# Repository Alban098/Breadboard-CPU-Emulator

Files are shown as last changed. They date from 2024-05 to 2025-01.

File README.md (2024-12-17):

# Breadboard CPU Emulator


## Compiler

This CLI will compile an assembly file into a .rom file that can be executed by the emulator and ran on the actual Breadboard computer (WIP).

See [assembly details](docs/assembly.md) for more details on the Assembly language itself.

### Usage
You can compile a file by passing the following parameter to the CLI of the compiler.
```
java -jar compiler.jar -f sample.asm -o sample.rom
```
if no ``-o X`` is passed, the binary file will be saved with the same name as the input file with a ``.rom`` extension.

## Emulator
The emulator is based on real world breadboard computer inspired by [this project](https://eater.net/8bit) that is not yet finished.

To run a binary file, just pass its path as an argument to the emulator.

### ROM & Instructions dumps
To facilitate physical assembly and proper emulation from instruction opcode down to signal indices in the control words,
the emulator has the ability to dump the content of it's program ROM, both in ["humanly readable format"](dump/ROM_dump.md) and as the binary blob that should be written to the 3 EEPROM that will be located in the **Control Unit** :
- [Dump 0](dump/ROM_dump.bin0) for the 8 least bits of the **Control Word**
- [Dump 1](dump/ROM_dump.bin1) for the 8 middle bits of the **Control Word**
- [Dump 2](dump/ROM_dump.bin2) for the 8 most significant bits of the **Control Word**

The emulator can also dump the [current instruction set](dump/instruction_set.md).

## Physical Computer
More details about the Breadboard computer in itself can be found [there](docs/modules.md), along with the full [parts list](docs/parts_list.md)

### EEPROM Programmer
That build uses some 28C series EEPROM to emulate large combinatorial logic, those will need to be programmed

I used that **EEPROM Programmer** : https://tomnisbet.github.io/TommyPROM/docs/hardware
If like me, you used an **Arduino Nano Every** instead of a **Nano V3** for the **EEPROM Programmer**, that Programmer will need some rework to actually work as intended (see [this repo](https://github.com/Alban098/TommyPROM-ATMEGA-4809) for the adapted code and wiring diagram)

## Roadmap
* [x] Instruction set
* [x] Assembly compiler
* [x] Emulator
  * [x] Components
  * [x] Signals
  * [x] Instructions
* [x] Documentation
* [x] Electrical diagrams
* [x] Electronic components ordering
* [ ] Physical assembly
  * [x] Clock module
  * [x] Program counter
  * [x] Registers
  * [x] ALU
  * [x] Status register
  * [x] Memory modules
  * [ ] Control Unit
  * [x] [Arduino Programmer](docs/programmer.md)

## Images




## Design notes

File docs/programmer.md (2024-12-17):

# 8 bits Breadboard Computer - Arduino Programmer

Having **64 KB of addressable space**, manually programming that computer through the **DIP switches everytime it is powered up** became unrealistic.
So the need for an automated way to upload programs became essential.

I was short on parts, so I had the idea of repurposing the **EEPROM programmer** used for the **Control Unit and the Output Register**. to also be able to program this Computer.

To achieve that, the simples way was to add 2 connection ports right next to the DIP switches, and to connect the **address and data pins** of the EEPROM Programmer, and hard-wiring the **Program Switch** to the **Write signal** of the EEPROM Programmer
This enables us to send binary files directly though **XMODEM protocols** using the serial port of the Arduino.

Doing it in that way introduced 2 limitations :
- First limitation of that approach is that we need to manually switch the Computer into programming mode for the process to actually succeed, 
- Second limitation is that we can't leverage the read capabilities of the EEPROM programmer as the DIP switch where we connected it are isolated from the RAM module output

Implementation details can be found [here](https://github.com/Alban098/TommyPROM-ATMEGA-4809)



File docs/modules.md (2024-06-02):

# 8 bits Breadboard Computer - Electronic diagrams

## Registers
This computer has **3 working registers**, used for general purpose computations, and an **output register**

### [A Register](modules/a_register.md)
This register is the main working register, it has **read** and **write** capabilities and is directly connected to the ALU.

Its main purpose is to store the **primary operand** of any computation.
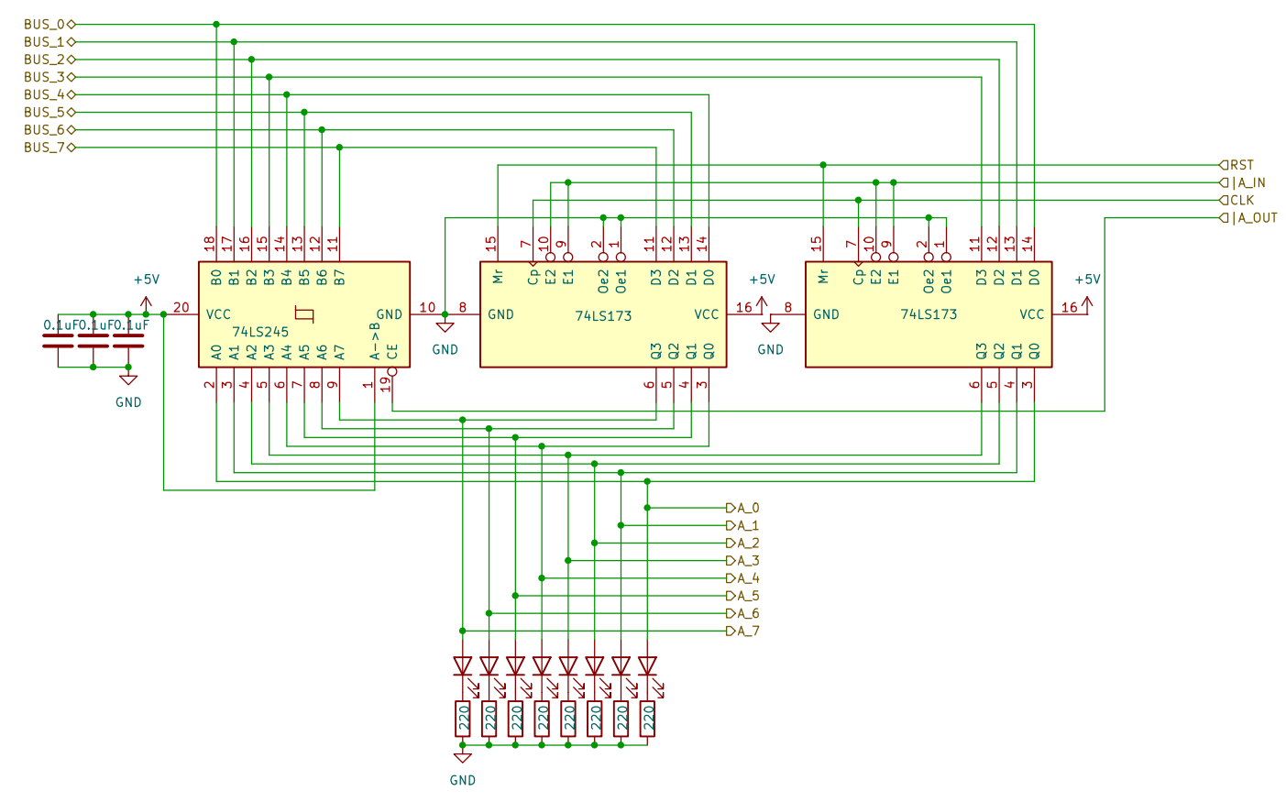
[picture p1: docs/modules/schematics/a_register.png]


### [B Register](modules/b_register.md)
This register is the secondary working register, it only has **write** capabilities and is directly connected to the ALU.

Its purpose is to store the **secondary operand** of any computation.
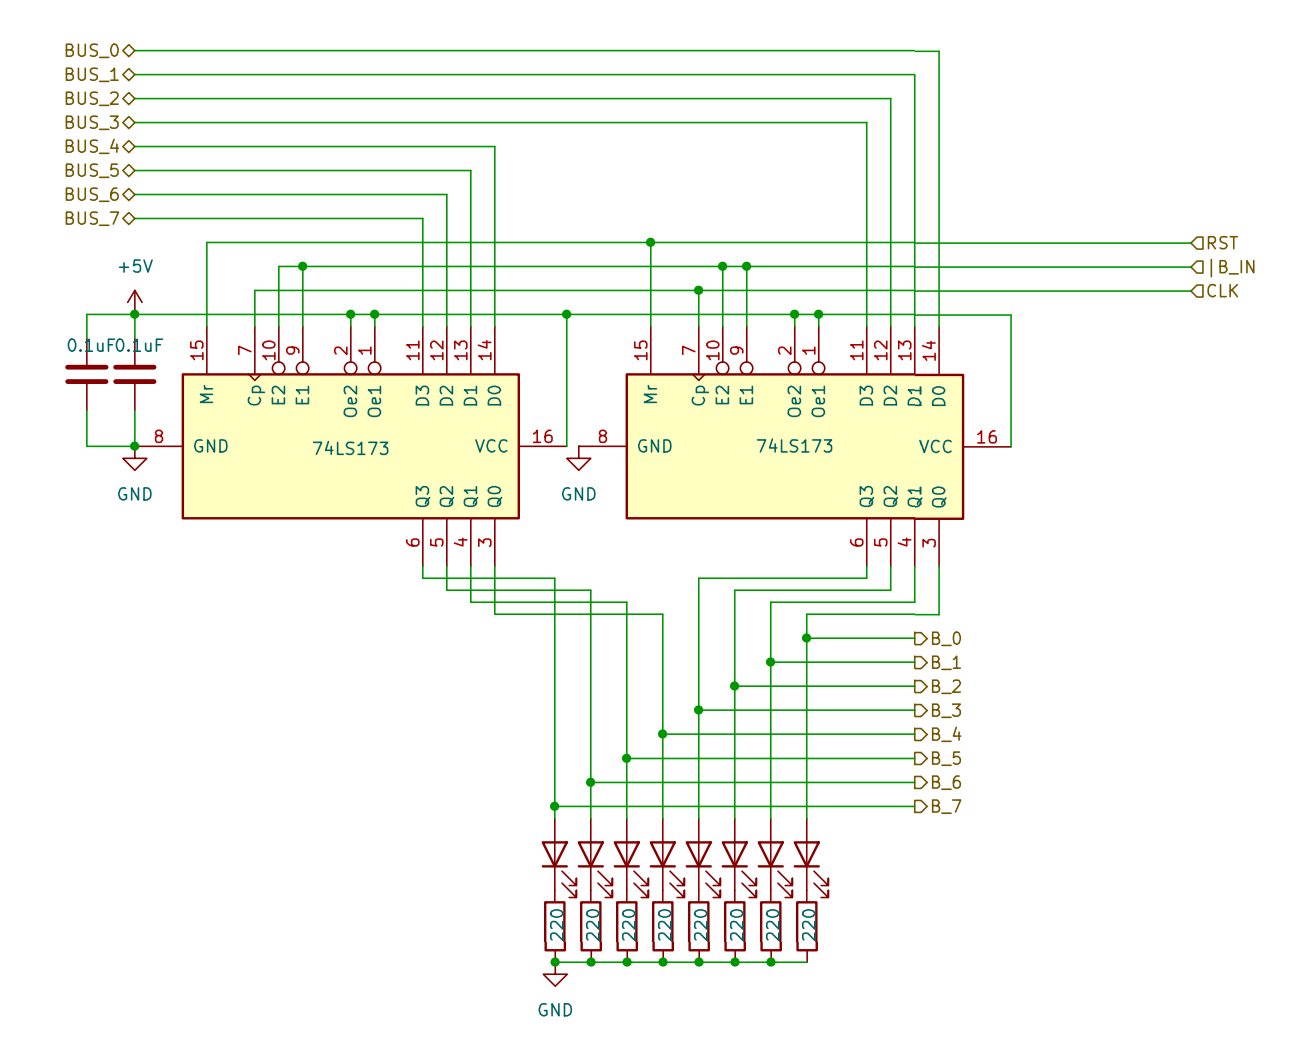
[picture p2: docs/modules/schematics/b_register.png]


### [HL Register](modules/hl_register.md)
This register is used to 'buffer' 16 bits memory addresses, 16 bits values can be written to it using only the 8 LSB of the BUS

It is widely used for memory addressing and branching instruction
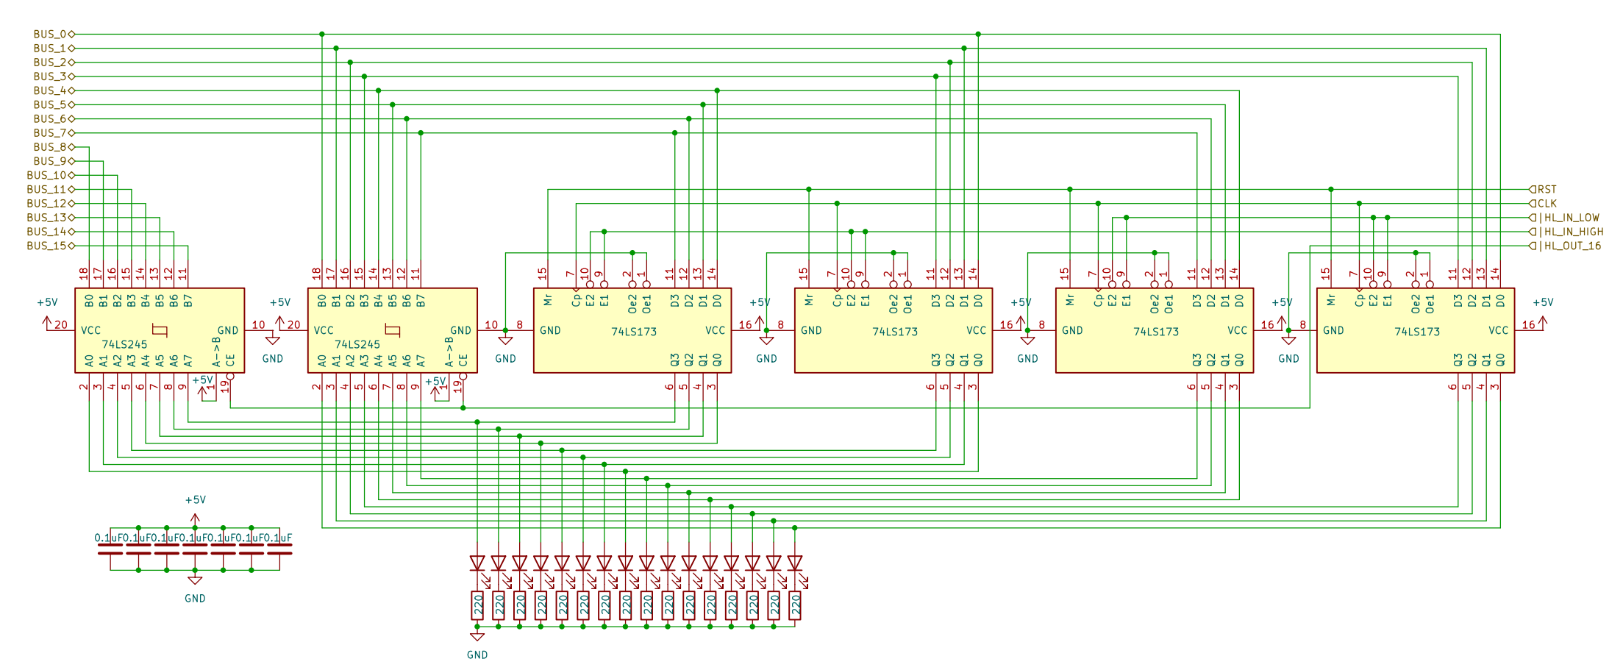
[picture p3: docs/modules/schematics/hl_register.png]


### [Output Register](modules/output_register.md)
This register has one purpose, to display the result of a computation in a user-friendly manner, it only has **write** capabilities and display can be switch from signed to unsigned. 
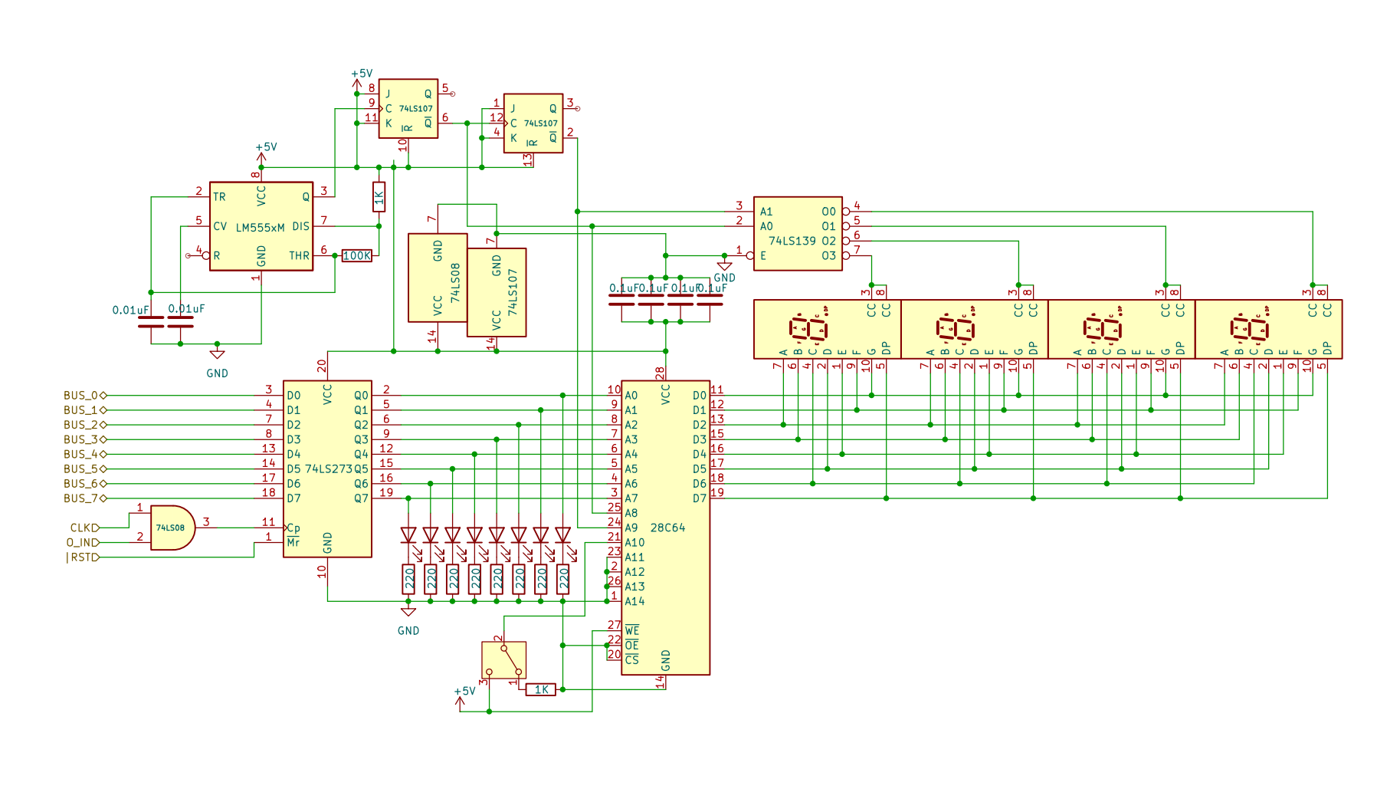
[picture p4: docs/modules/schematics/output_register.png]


## Memory Management
In this computer, **RAM reads and writes** are totally **synchronous**, and no slower to access than any registers.
Memory address is selected using the **Memory Address Register** after that, **Memory** operate juste like any other register.

### [Memory Address Register](modules/memory_address_register.md)
This register's only purpose is to hold the currently selected memory address, it's output is directly connected to the address lines of the **Memory module**

It also holds control over "Manual programming mode" using a static switch, in this state, the memory address pointer is controller by 2 8DIP switch.

This register can hold a 16 bits address
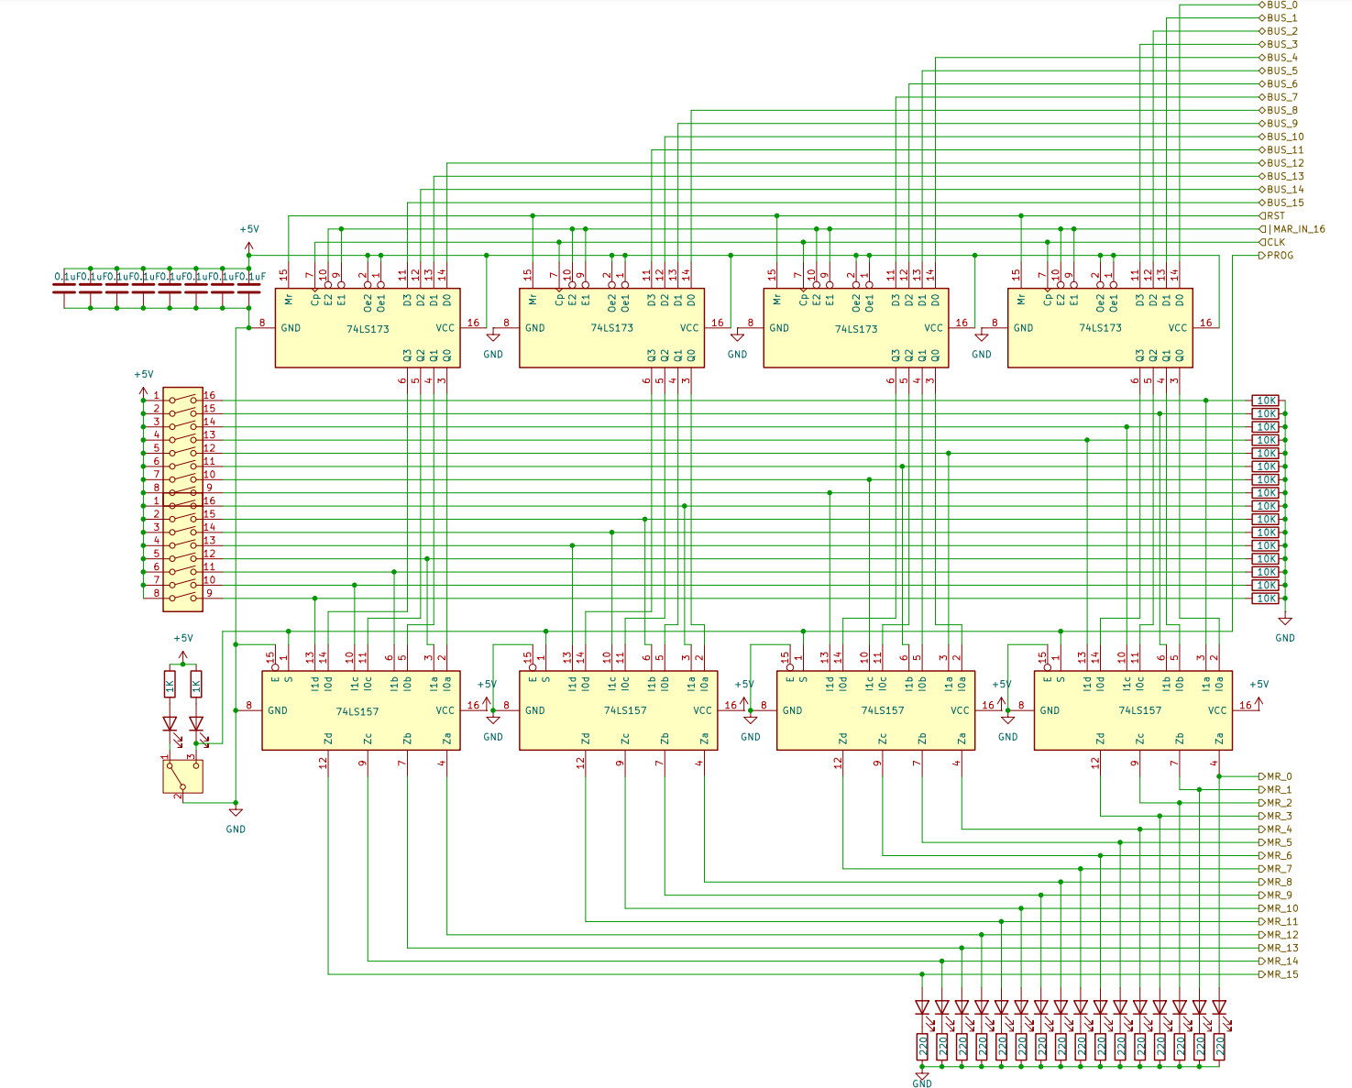
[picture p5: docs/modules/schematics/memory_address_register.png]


### [Memory](modules/memory.md)
The memory module is responsible to hold all the data of the computer and should be capable of being addressed by an 8 bit value.

This module is enslaved to the **Memory Address Register**'s **Manual programming mode** switch, in this state, the written value is controlled by an 8DIP switch.
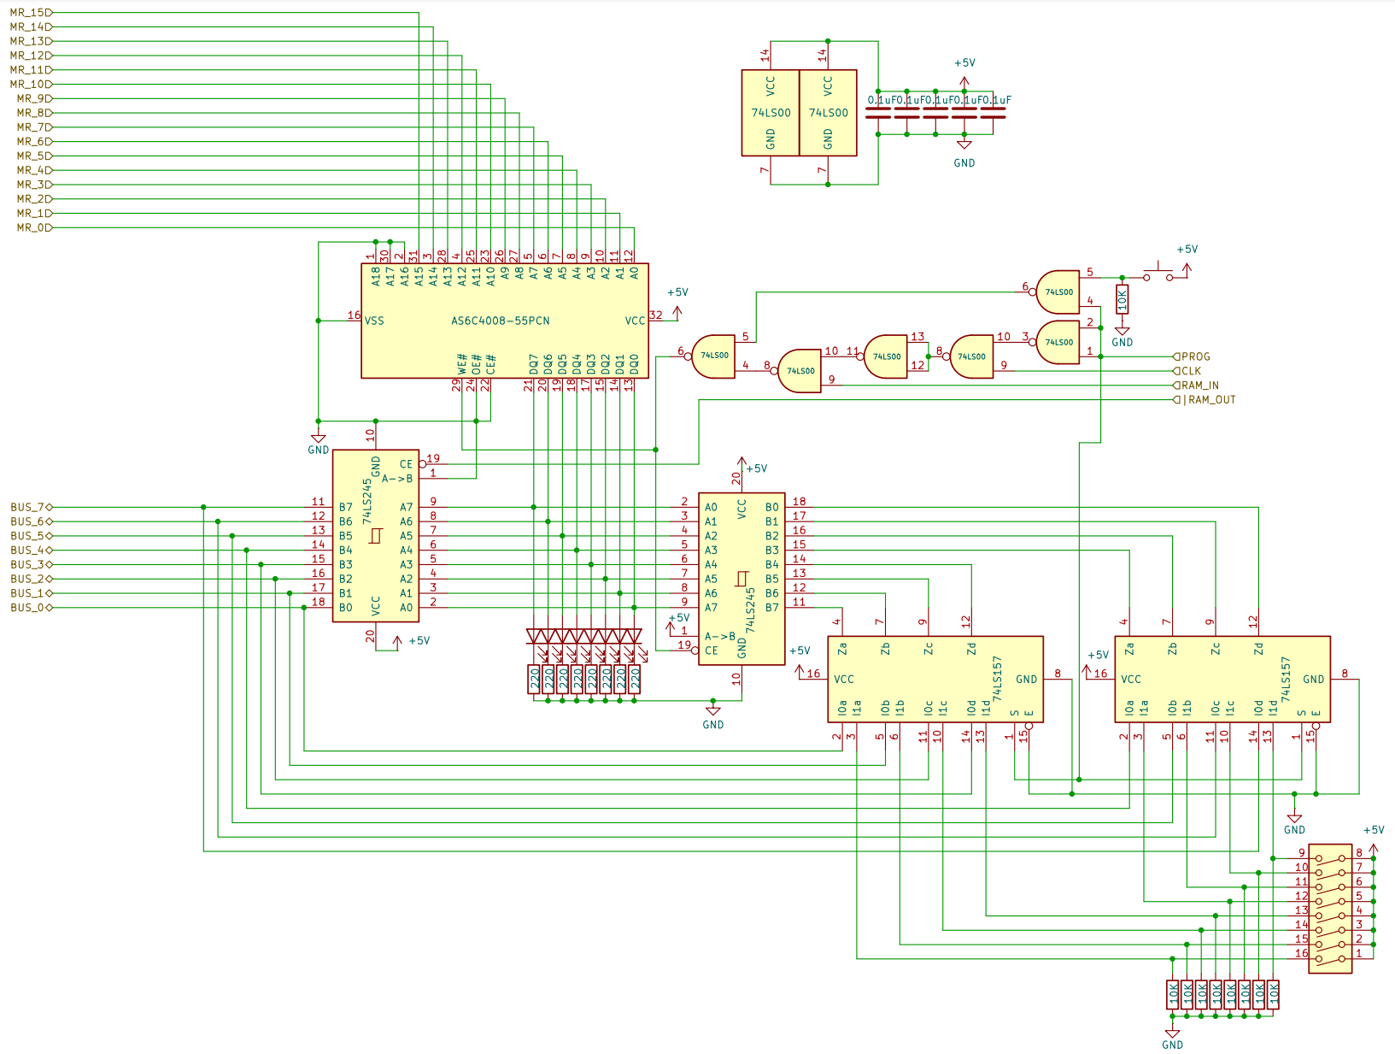
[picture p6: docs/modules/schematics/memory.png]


## Execution Logic
The execution logic is composed of 3 primary components, responsible for addressing, executing and keeping track of the current state and instructions.

### [Program Counter](modules/program_counter.md)
The program counter is responsible for keeping track of where in the execution the computer currently is, it has the ability to be programmatically set by branching instructions

The program counter can count up to #FFFF, and is one of the few modules that can exploit the entire 16 bit bus
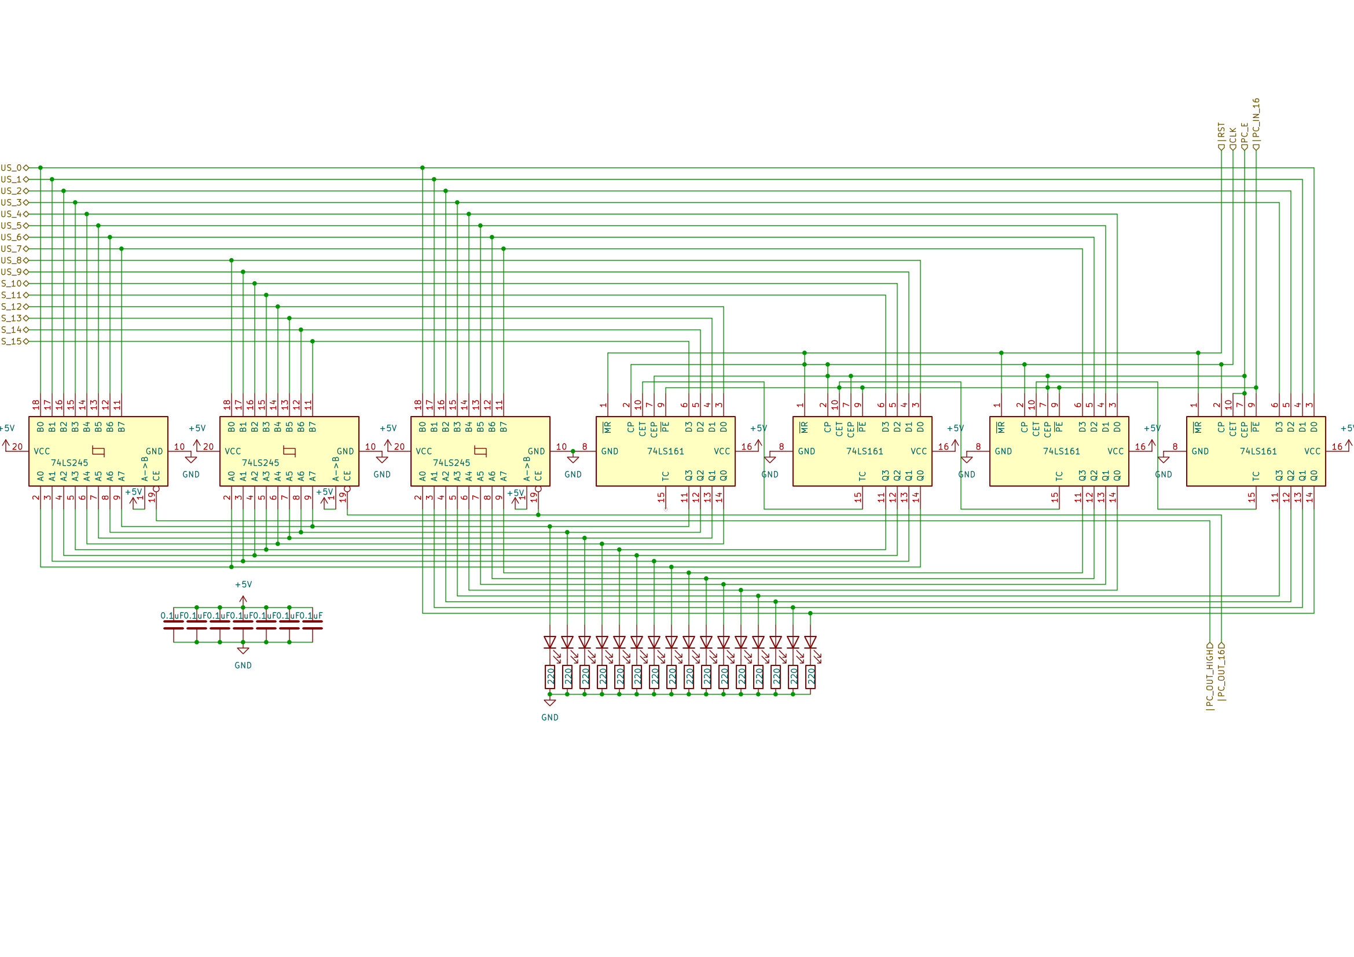
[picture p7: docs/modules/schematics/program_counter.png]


### [Arithmetic Unit](modules/alu.md)
The alu is the main brain of the computer, it's the component that actually perform computation and is the only way to interact with the status register and execute conditional branching instructions
It has 2 modes, the first being simple addition, the second being 2's complement subtraction (A - B)
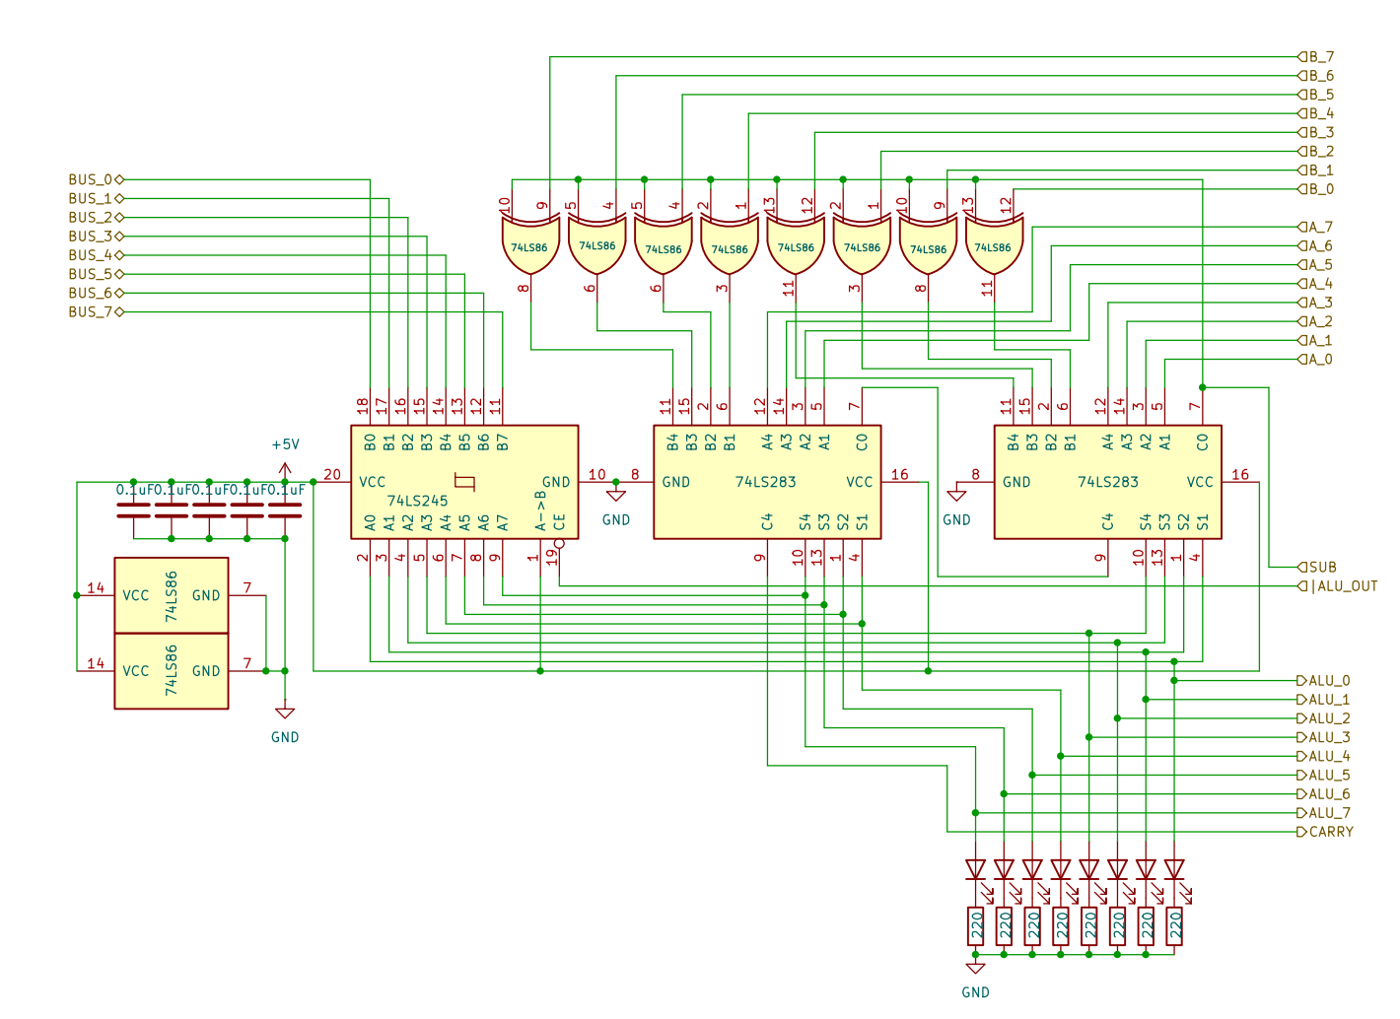
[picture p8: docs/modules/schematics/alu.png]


### [Status Register](modules/status_register.md)
The last component of the execution logic is the status register, it holds **Flags** regarding the last computation.

The 4 flags are :
- **Overflow** if the result has changed sign, this flag is only relevant if you consider your values as signed integers.
- **Zero** if the result of the computation is 0.
- **Carry** if the previous operation has produced a carry to ripple out of the 8 bit range.
- **Negative** if the most significant bit of the result is set to 1, meaning a negative number if in signed mode .
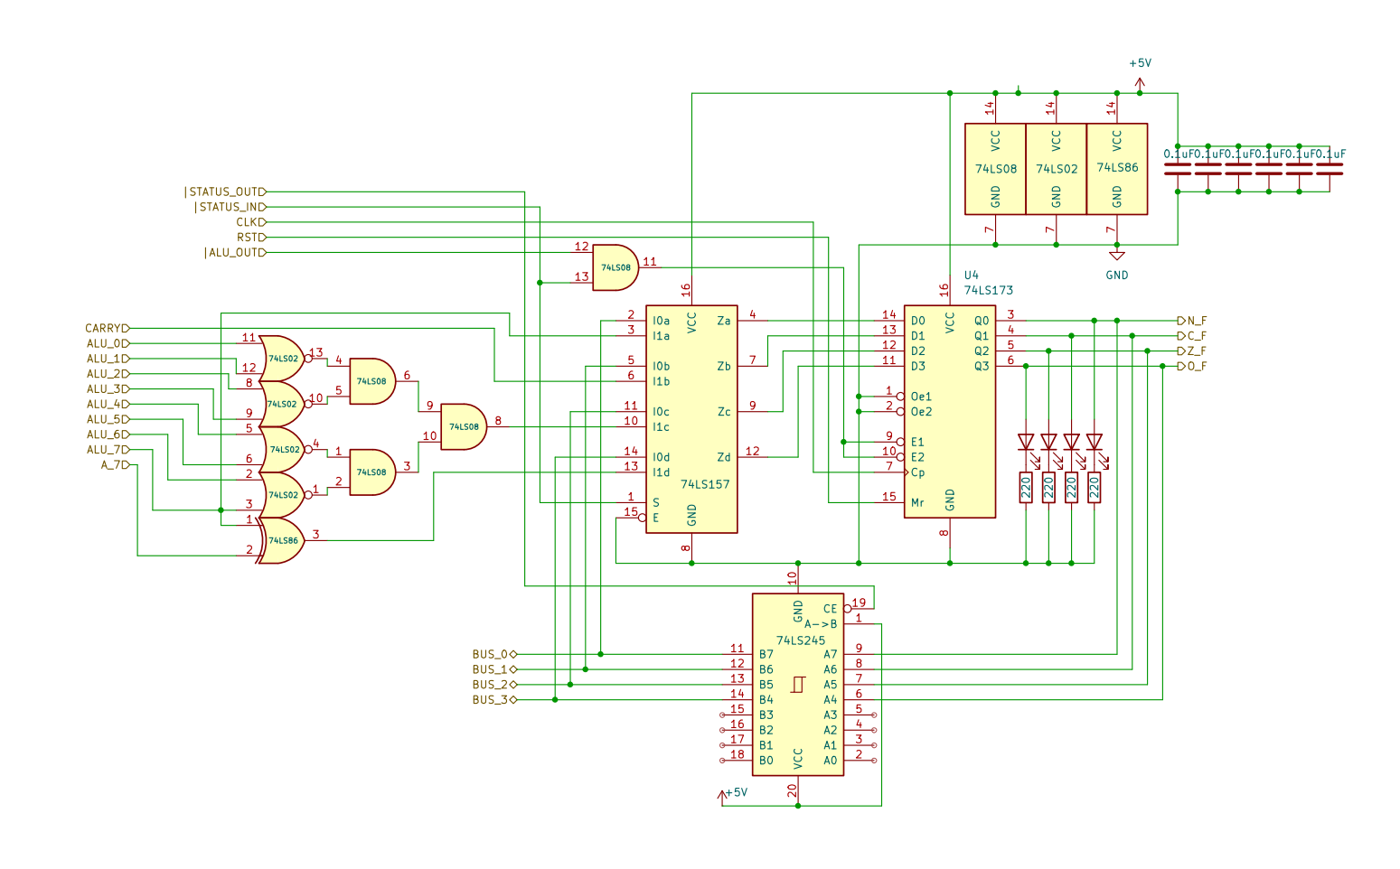
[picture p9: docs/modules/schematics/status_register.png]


### [Stack Pointer](modules/stack_pointer.md)
This register is used to hold the current stack pointer, it is hardware wise an 8 bits register, but is read as a 16bit register, with the 8 MSB set to HIGH, effectively this restricts the stack to the last memory page

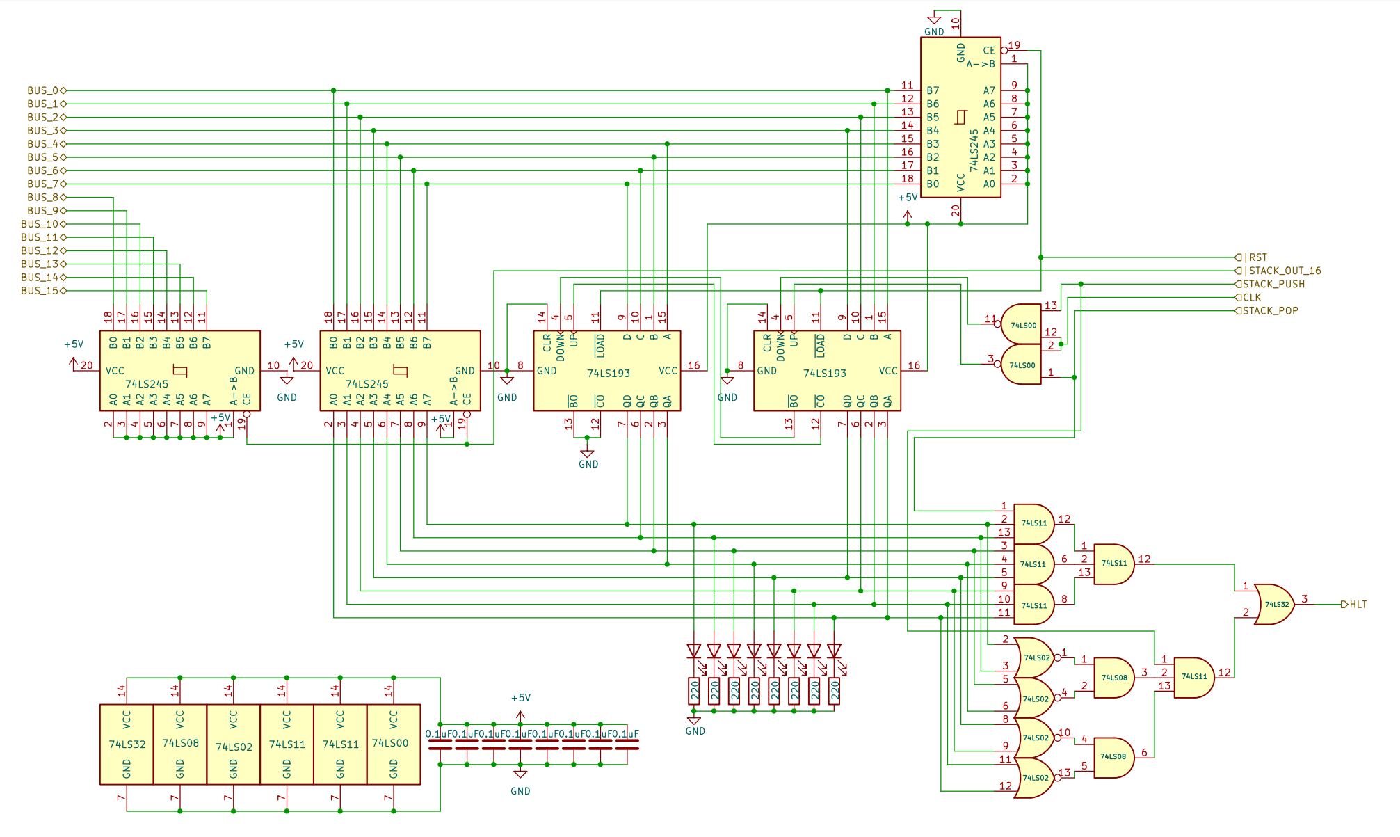
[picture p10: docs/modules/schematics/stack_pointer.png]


## Control Logic
The last key part of the computer, is the control logic that will enable every component to work together as one unit.

### [Clock Module](modules/clock.md)
The clock module is at the bottom of the pyramid, it dictat the rythme to all other component and synchronize them.

This module can operate on itself or switch to "Manual" mode, in which the clock signal is controller by a psh button for debug purposes.
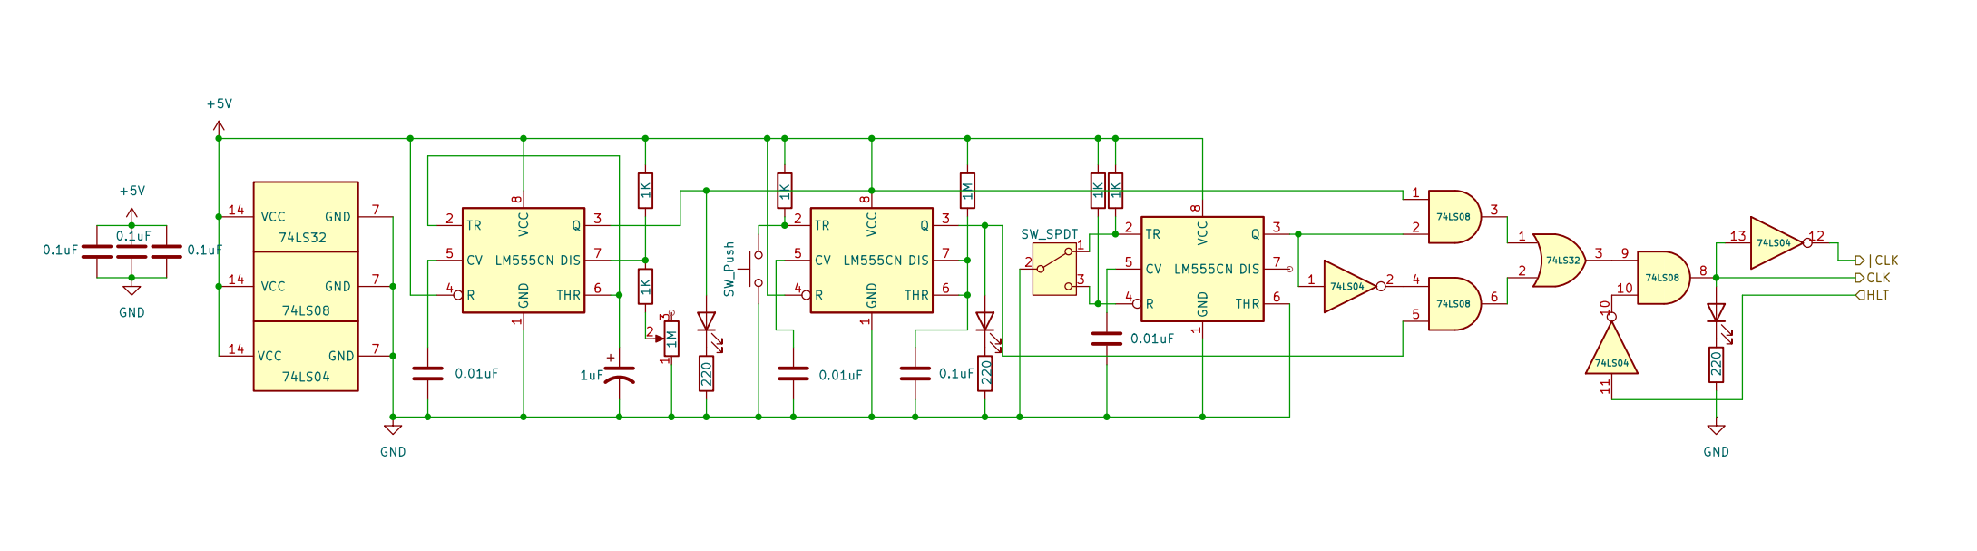
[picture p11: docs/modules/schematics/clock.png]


### [Instruction Register](modules/instruction_register.md)
The instruction register is similar to the **Memory Address Register** but hold the opcode of the currently executing instruction.

Its output is directly connected to the **Control Unit**
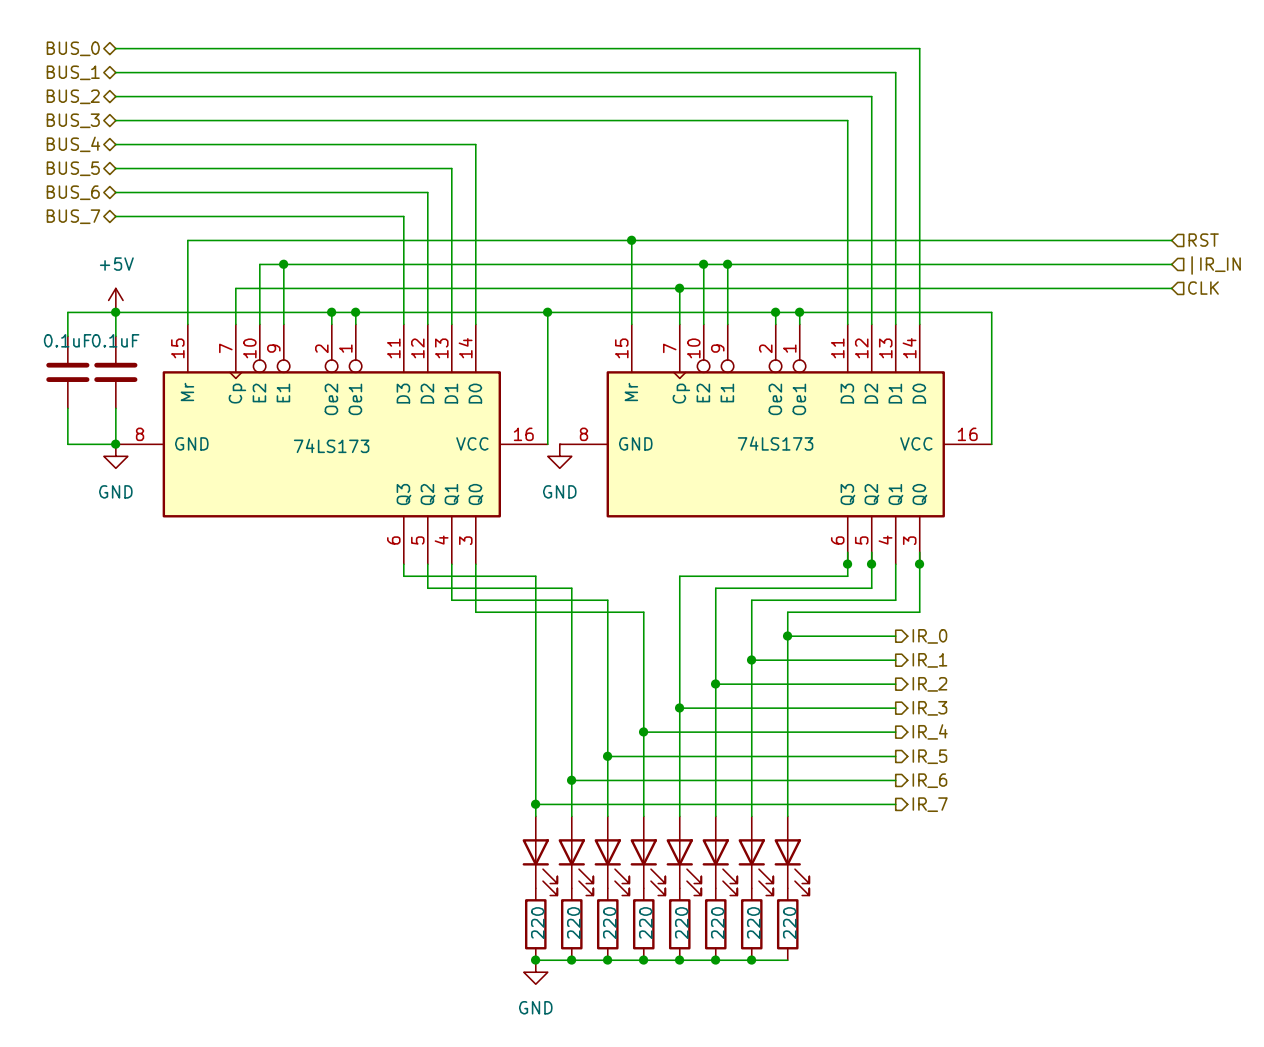
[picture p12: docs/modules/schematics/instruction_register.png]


### [Control Unit](modules/control_unit.md)
Finally, the last component is one of the most important, as it will tell each other component, what to do and when to do it depending on the current execution context 
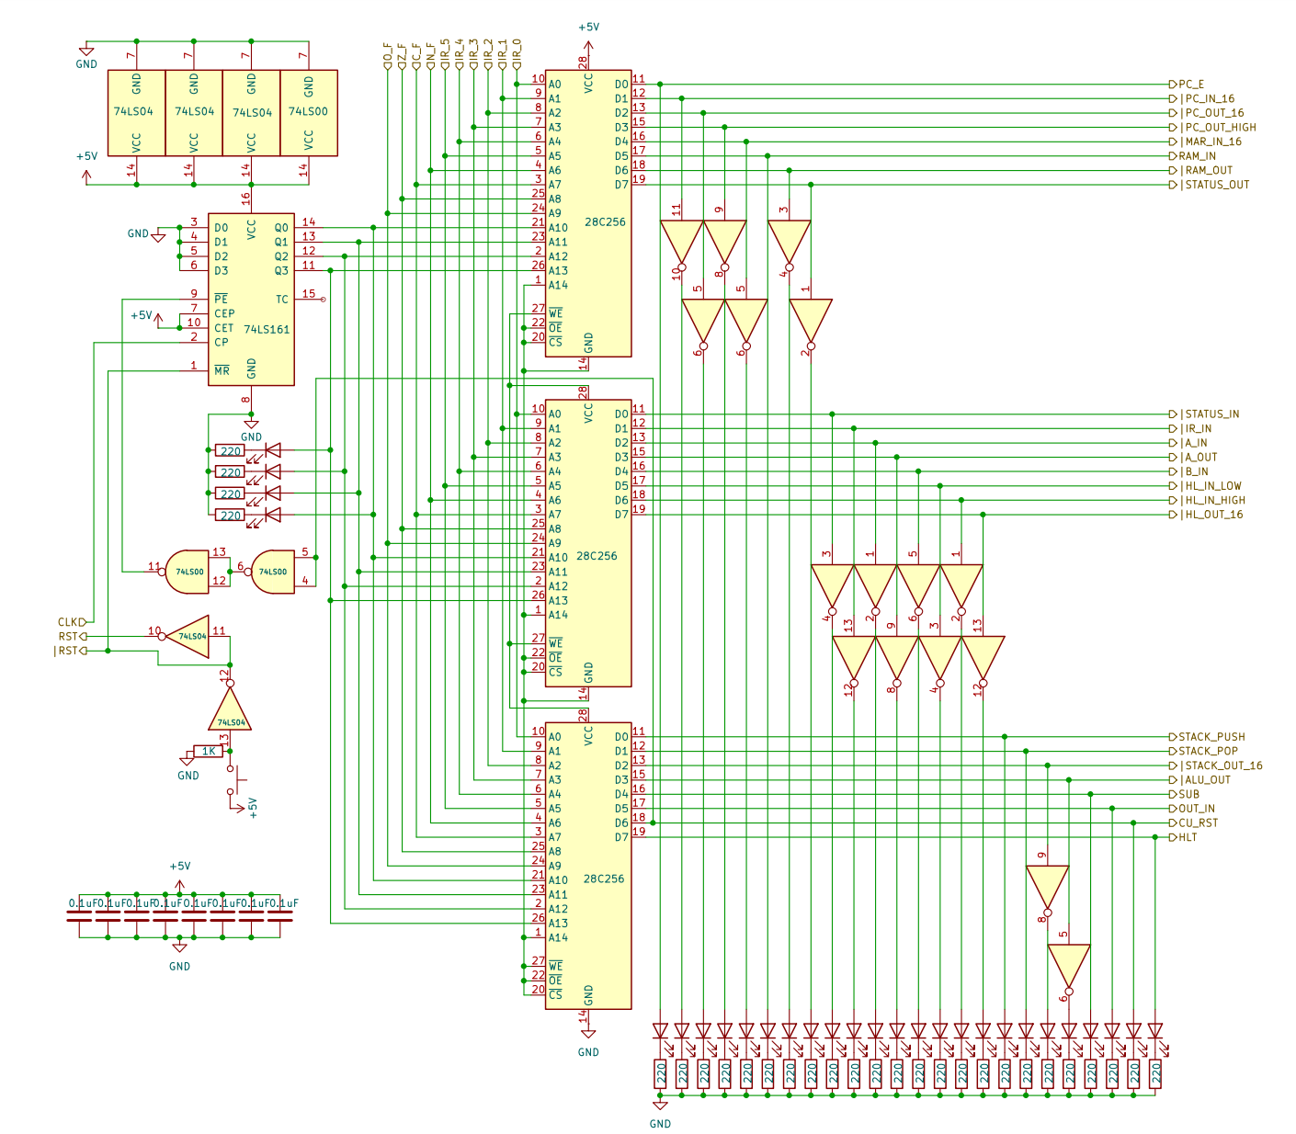
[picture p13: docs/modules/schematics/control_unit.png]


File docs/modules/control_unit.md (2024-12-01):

# 8 bits Breadboard Computer - Control Unit

## Diagram


## Description
Internally, each instruction has a certain number of micro-steps, this is handled by a 4bits counter that will keep track of the current micro-step.
Each instruction should therefore have a last micro-step that is responsible for resetting the counter.

The 3 EEPROMs are used as combinational logic substitutes, the address is of the form
```
Step(4bit)_Flags(4bit)_opcode(6bit)
```
The RST signal is controlled by a Push Switch on this module
The CLK signal will be used to increase the Step Counter

A subset of signals is inverted, this is due to the fact that in their respective modules, they are **Active_LOW**, due to that, the EEPROM will default them to 1 and set them to 0, this way, we only need inverters for displaying purposes, but they can be removed from the build if not needed

! In the Emulator, state represent what is displayed and not what actually is in the EEPROM, all signals are considered **ACTIVE_HIGH** by the Emulator !

### Signals
| Signal | Mode | Binary mask | Description |
|:---|---:|:---:|---:|
| CLK | Active_HIGH | X | The main clock signal |

### I/O
| Name | Size | Type | Description |
|:-----|---:|-----:|---:|
| IR | 6 bits | In | The 6 least significant bits of the Instruction Register |
| *_F  | 4 bits | In | The 4 least significant bits of the Status Register |

## Parts list
| Part | Quantity |
|:---|---:|
| Breadboard BB830 | 3 |
| 220Ω Resistor | 28 |
| 0,1µF Capacitor | 8 |
| CD74HCT00E (4x 2-NANDs) | 1 |
| CD74HCT04E (8x Inverters) | 3 |
| CD74HCT161E (4 bits Counter) | 1 |
| AT28C256-15PU | 3 |
| Yellow LED | 4 |
| Blue LED | 24 |
| Push Button | 1 |

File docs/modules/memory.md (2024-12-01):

# 8 bits Breadboard Computer - Memory

## Diagram


## Description
The module can be switched in **Manual Programming Mode** (this is controlled by the Memory Address Register), in that state, the value read from the bus is overridden by a 8DIP Switch, and the clock and **RAM_IN** signals are overridden by a Push Switch.

### Signals
| Signal  | Mode | Binary mask | Description |
|:---|---:|:---:|---:|
| RAM_IN  | Active_HIGH | 0000_0000_0010_0000 | Will capture the BUS's value at the next @CLK and store it at the selected address |
| RAM_OUT |  Active_LOW | 0000_0000_0100_0000 | Puts the current value at the selected address on the BUSS |
| PROG | Active_HIGH | X | Will set the module in **Manual Programming Mode** |
| CLK | Active_HIGH | X | The main clock signal |

### I/O
| Name | Size | Type | Description |
|:-----|---:|---:|---:|
| BUS  |  8 bits | In / Out | Direct connection to the BUS |
| MAR  | 16 bits | In | Direct output of the **Memory Address Register** |

## Parts list
| Part | Quantity |
|:---|---:|
| Breadboard BB830 | 2 |
| 220Ω Resistor | 8 |
| 10kΩ Resistor | 9 |
| 1nF Capacitor | 1 |
| 0,1µF Capacitor | 5 |
| CD74HCT00E (4x 2-NANDs) | 2 |
| CD74HCT157E (2 lines to 1 bit Encoder) | 2 |
| CD74HCT245E (8 bits Bus Transceiver) | 2 |
| AS6C1008-55PIN | 1 |
| Red LED | 8 |
| 8 bits DIP switch | 1 |

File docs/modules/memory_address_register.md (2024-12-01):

# 8 bits Breadboard Computer - Memory Address Register

## Diagram


## Description
This register holds the pointer of the current RAM address, it also controls the **Manual Programming Mode** switch

### Signals
| Signal | Mode | Binary mask | Description |
|:---|---:|:---:|---:|
| MAR_IN_16 |  Active_LOW | 0000_0000_0000_0000_0001_0000 | Will capture the BUS's value at the next @CLK |
| RST | Active_HIGH | X | Reset the register's value to 0 |
| CLK | Active_HIGH | X | The main clock signal |

### I/O
| Name | Size | Type | Description |
|:-----|---:|-----:|---:|
| BUS  | 16 bits | In | Direct connection to the BUS |
| MR | 16 bits |  Out | Output of the register |
| PROG |  1 bits |  Out |  Will set the module in **Manual Programming Mode** |

## Parts list
| Part | Quantity |
|:---|---:|
| Breadboard BB830 | 2 |
| 220Ω Resistor | 16 |
| 1kΩ Resistor | 2 |
| 10kΩ Resistor | 16 |
| 0,1µF Capacitor | 8 |
| CD74HCT173E (4 bits Register) | 4 |
| CD74HCT157E (2 lines to 1 bit Encoder) | 4 |
| Yellow LED | 1 |
| Green LED | 1 |
| Red LED | 16 |
| 8 bits DIP switch | 2 |
| Toggle Switch | 1 |

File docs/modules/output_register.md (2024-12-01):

# 8 bits Breadboard Computer - Output Register

## Diagram


## Description
This register will display its value as a decimal value that can be signed or not.

It will drive 4 7 segments display using the same data lines and one EEPROM. this is managed by rapidly switching on and off each display and relying on persistence of vision.

To do so we use a 555 Timer to get a consistent clock signal, and use 2 JK-Flip-Flop to simulate a 2 bit binary counter, this value is used as the 2 MSB of the EEPROM Address to differentiate each digit of a number.
We also use a 2bit to 4 lines selector to activate and deactivate each display one at a time.
This will have the effect of making each display show a different number, creating the illusion of driving all the 7 segment displays at the same time with a quarter of the data lines 

A Switch can control if the value is displayed as signed or not.

! Don't forget to tie signals of the additional flip-flop of the 74HCT107 to GND to avoid potential interference in the display !

Find [here](../../dump/output_register_eeprom_dump.bin) the EEPROM content associated with this wiring

### Signals
| Signal | Mode | Binary mask | Description |
|:---|---:|:---:|---:|
| OUT_IN | Active_HIGH | 0010_0000_0000_0000_0000_0000 | Will capture the BUS's value at the next @CLK |
| RST |  Active_LOW | X | Reset the register's value to 0 |
| CLK | Active_HIGH | X | The main clock signal |

### I/O
| Name | Size | Type | Description |
|:-----|---:|---:|---:|
| BUS  | 8 bits | In | Direct connection to the BUS |

## Parts list
| Part | Quantity |
|:---|---:|
| Breadboard BB830 | 2 |
| 220Ω Resistor | 8 |
| 1kΩ Resistor | 2 |
| 100kΩ Resistor | 1 |
| 0,01µF Capacitor | 2 |
| 0,1µF Capacitor | 4 |
| LM555CN (Timer) | 1 |
| CD74HCT08E (4x 2-ANDs) | 1 |
| CD74HCT107E (Dual JK-Flip-Flops) | 1 |
| CD74HCT139E (2 bits to 4 lines Decoder) | 1 |
| CD74HCT273E (8x D-Flip-Flops) | 1 |
| AT28C64B-15PU | 1 |
| Red LED | 8 |
| Toggle Switch | 1 |
| 7 Segments Display | 4 |

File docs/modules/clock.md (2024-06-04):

# 8 bits Breadboard Computer - Clock Module

## Diagram


## Description
The 3 LM555CM timers each have a different purpose :
- The first one is in **astable** mode, providing a regular clock signal that is length controllable using the variable resistor.
- The second one is a **monostable** and serve as a filter to debounce the Push Switch's clock signal will manual stepping.
- The last one is a **bistable** and serve the same purpose as the monostable one but for the mode switching switch.

### Signals
| Signal | Mode | Binary mask | Description |
|:---|---:|:---:|---:|
| HLT | Active_HIGH | 1000_0000_0000_0000_0000_0000 | Prevent any clock cycle from occurring |

### I/O
| Name | Size | Type | Description |
|:-----|---:|---:|---:|
| CLK  | 1 bits | Out | The main clock signal |
| ~CLK | 1 bits | Out | The main clock signal, but inverted |

## Parts list
| Part | Quantity |
|:---|---:|
| Breadboard BB830 | 1 |
| 220Ω Resistor | 3 |
| 1kΩ Resistor | 5 |
| 1MΩ Resistor | 1 |
| 1MΩ Potentiometer | 1 |
| 0,1µF Capacitor | 4 |
| 0,01µF Capacitor | 3 |
| 1µF Capacitor | 1 |
| Toggle Switch | 1 |
| Push Button | 1 |
| LM555CN (Timer) | 3 |
| CD74HCT04E (8x Inverters)  | 1 |
| CD74HCT08E (4x 2-ANDs) | 1 |
| CD74HCT32E (2x 4-ORs) | 1 |
| Green LED | 2 |
| Blue LED | 1 |

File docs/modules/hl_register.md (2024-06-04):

# 8 bits Breadboard Computer - HL Register

## Diagram


## Description

### Signals
| Signal | Mode | Binary mask | Description |
|:---|---:|:---:|---:|
| HL_IN_LOW  |  Active_LOW | 0000_0000_0010_0000_0000_0000 | Will capture the BUS's value in the 8 LSB at the next @CLK |
| HL_IN_HIGH |  Active_LOW | 0000_0000_0100_0100_0000_0000 | Will capture the BUS's value in the 8 MSB at the next @CLK |
| HL_OUT_16  |  Active_LOW | 0000_0000_1000_1000_0000_0000 | Writes the current value to the BUS |
| RST | Active_HIGH | X | Reset the register's value to 0 |
| CLK | Active_HIGH | X | The main clock signal |

### I/O
| Name | Size | Type | Description |
|:-----|---:|---:|---:|
| BUS  | 16 bits | In / Out | Direct connection to the BUS |
| A |  8 bits | Out | Output of the register, before the Transceiver |

## Parts list
| Part | Quantity |
|:---|---:|
| Breadboard BB830 | 1 |
| 220Ω Resistor | 16 |
| 0,1µF Capacitor | 6 |
| CD74HCT173E (4 bits Register) | 4 | 
| CD74HCT245E (8 bits Bus Transceiver) | 2 |
| Red LED | 16 |

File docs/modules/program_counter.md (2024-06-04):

# 8 bits Breadboard Computer - Program Counter

## Diagram


## Description
The 4 CD74HCT161E are connected in series, to achieve a 16 bit binary counter.

### Signals
| Signal | Mode | Binary mask | Description |
|:---|---:|:---:|---:|
| PC_E | Active_HIGH | 0000_0000_0000_0000_0000_0001 | Will count up one at the next @CLK |
| PC_IN_16 |  Active_LOW | 0000_0000_0000_0000_0000_0010 | Will capture the BUS's value at the next @CLK |
| PC_OUT_16 |  Active_LOW | 0000_0000_0000_0000_0000_0100 | Writes the current value to the BUS (all 16 bits) |
| PC_OUT_HIGH |  Active_LOW | 0000_0000_0000_0000_0000_1000 | Writes the 8 MSB current value to the 8 LSB of the BUS |
| RST |  Active_LOW | X | Reset the register's value to 0 |
| CLK | Active_HIGH | X | The main clock signal |

### I/O
| Name | Size | Type | Description |
|:-----|---:|---:|---:|
| BUS  | 16 bits | In / Out | Direct connection to the BUS |

## Parts list
| Part | Quantity |
|:---|---:|
| Breadboard BB830 | 2 |
| 220Ω Resistor | 16 |
| 0,1µF Capacitor | 7 |
| CD74HCT161E (4 bits Counter) | 4 |
| CD74HCT245E (8 bits Bus Transceiver) | 3 |
| Red LED | 16 |

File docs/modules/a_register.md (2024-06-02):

# 8 bits Breadboard Computer - A Register

## Diagram


## Description

### Signals
| Signal | Mode | Binary mask | Description |
|:---|---:|:---:|---:|
| A_IN |  Active_LOW | 0000_0000_0000_0100_0000_0000 | Will capture the BUS's value at the next @CLK |
| A_OUT  |  Active_LOW | 0000_0000_0000_1000_0000_0000 | Writes the current value to the BUS |
| RST | Active_HIGH | X | Reset the register's value to 0 |
| CLK | Active_HIGH | X | The main clock signal |

### I/O
| Name | Size | Type | Description |
|:-----|---:|---:|---:|
| BUS  | 8 bits | In / Out | Direct connection to the BUS |
| A | 8 bits | Out | Output of the register, before the Transceiver |

## Parts list
| Part | Quantity | Unit Price |
|:---|---:|---:|
| Breadboard BB830 | 1 | 8,12 € |
| 220Ω Resistor | 8 | 0,02 € |
| 0,1µF Capacitor | 3 | 0,37 € |
| CD74HCT173E (4 bits Register) | 2 | 0,73 € | 
| CD74HCT245E (8 bits Bus Transceiver) | 1 | 0,80 € |
| Red LED | 8 | 0,12 € |

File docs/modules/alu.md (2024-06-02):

# 8 bits Breadboard Computer - Arithmetic Unit

## Diagram


## Description
The 2 SN74LS86AN are used to convert B into it's 2's complement for SUB mode

### Signals
| Signal  | Mode | Binary mask | Description |
|:---|---:|:---:|---:|
| ALU_OUT |  Active_LOW | 0000_1000_0000_0000_0000_0000 | Writes the current value to the BUS |
| SUB | Active_HIGH | 0001_0000_0000_0000_0000_0000 |  Subtract B from A, result is signed integer |

### I/O
| Name  | Size | Type | Description |
|:---|---:|---:|---:|
| BUS | 8 bits | In / Out | Direct connection to the BUS |
| A | 8 bits | In | Direct input from the A Register, before transceiver |
| B | 8 bits | In | Direct input from the B Register |
| ALU | 8 bits | Out | Output of the ALU, before the Transceiver |
| Carry | 1 bits | Out | High if a carry has rippled out of the 8 bit range |

## Parts list
| Part | Quantity | Unit Price | 
|:---|---:|---:|
| Breadboard BB830 | 1 | 8,12 € |
| 220Ω Resistor | 8 | 0,02 € |
| 0,1µF Capacitor | 5 | 0,37 € |
| CD74HCT86E  (4x 2-XORs) | 2 | 0,81 € |
| CD74HCT245E (8 bits Bus Transceiver) | 1 | 0,80 € |
| CD74HCT283E (4 bits Full Adder) | 2 | 0,90 € |
| Red LED | 8 | 0,12 € |

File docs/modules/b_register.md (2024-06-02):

# 8 bits Breadboard Computer - B Register

## Diagram


## Description
This register has no bus output because of technical limitations (signal count must be kept under 24)

### Signals
| Signal | Mode | Binary mask | Description |
|:---|---:|:---:|---:|
| B_IN |  Active_LOW | 0000_0000_0001_0000_0000_0000 | Will capture the BUS's value at the next @CLK |
| RST | Active_HIGH | X | Reset the register's value to 0 |
| CLK | Active_HIGH | X | The main clock signal |

### I/O
| Name | Size | Type | Description |
|:-----|---:|---:|---:|
| BUS  | 8 bits | In | Direct connection to the BUS |
| B | 8 bits | Out | Output of the register |

## Parts list
| Part | Quantity | Unit Price |
|:---|---:|---:|
| Breadboard BB830 | 1 | 8,12 € |
| 220Ω Resistor | 8 | 0,02 € |
| 0,1µF Capacitor | 2 | 0,37 € |
| CD74HCT173E (4 bits Register) | 2 | 0,73 € |
| Red LED | 8 | 0,12 € |

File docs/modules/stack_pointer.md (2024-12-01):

# 8 bits Breadboard Computer - Stack Pointer

## Diagram


## Description
The ``HTL`` signal will be pulled HIGH if an operation that will trigger an overflow is requested (thus preventing the next clock cycle from occurring) :
- All bits are 0 and the ``STACK_PUSH`` is HIGH (this would trigger a roll-over from #00 to #FF, when decrementing)
- All bits are 1 and the ``STACK_POP`` is HIGH (this would trigger an overflow from #FF to #00, when incrementing)

The reset signal is tight to a CD74HCT245E because à reset of the stack pointer should set it to the top of the stack address space, which is #FF,
so when ``RST`` is triggered, we force-feed that value onto the bus, this should not cause any harm as when resetting, nothing else should read from the bus.

### Signals
| Signal | Mode | Binary mask | Description |
|:---|---:|:---:|---:|
| STACK_PUSH | Active_HIGH | 0000_0001_0000_0000_0000_0000 | Will increment the value on the next @CLK |
| STACK_POP | Active_HIGH | 0000_0010_0000_0000_0000_0000 | Will decrement the value on the next @CLK |
| STACK_OUT_16 | Active_LOW | 0000_0100_0000_0000_0000_0000 | Writes the current value to the BUS prepended with #FF |
| RST | Active_HIGH | X | Reset the register's value to #FFFF |
| CLK | Active_HIGH | X | The main clock signal |

### I/O
| Name | Size | Type | Description |
|:-----|---:|---:|---:|
| BUS  | 16 bits | In / Out | Direct connection to the BUS |

## Parts list
| Part | Quantity |
|:---|---:|
| Breadboard BB830 | 2 |
| 220Ω Resistor | 8 |
| 0,1µF Capacitor | 7 |
| CD74HCT245E (8 bits Bus Transceiver) | 3 |
| CD74HCT00E (4x 2-NANDs) | 1 |
| CD74HCT02E (4x 2-NORs) | 1 |
| CD74HCT08E (4x 2-ANDs) | 1 |
| CD74HCT11E (3x 3-ANDs) | 2 |
| CD74HCT32E (4x 2-ORs) | 2 |
| CD74HCT193E (4 bits UP/DOWN Counter) | 2 |
| Red LED | 8 |

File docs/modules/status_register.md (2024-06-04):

# 8 bits Breadboard Computer - Status Register

## Diagram


## Description
The status register is responsible for capturing the state of the ALU's flags after certain instructions.
#### Overflow
If the result has changed sign, this flag is only relevant if you consider your values as signed integers.

This flag will be set if the 8th bit of the A Register is different from the 8th bit of the result, we can compute is as follows ``(A_8 ^ R_8) != 0``

#### Zero 
If the result of the computation is 0.

This flag is set when all bits of the Result are 0, we can compute is as follows ``(~(R_0 | R_1) & ~(R_2 | R_3)) &(~(R_4 | R_5) & ~(R_6 | R_7))``
#### Carry 
If the previous operation has produced a carry to ripple out of the 8 bit range.

This flag is simply captured from the ALU's output **CARRY** signal

#### Negative 
If the most significant bit of the result is set to 1, meaning a negative number if in signed mode .

This flag is simply captured as the 8th bit of the result 

### Signals
| Signal | Mode | Binary mask | Description |
|:---|---:|:---:|---:|
| STATUS_IN  |  Active_LOW | 0000_0000_0000_0001_0000_0000 | Will capture the BUS's value at the next @CLK |
| STATUS_OUT |  Active_LOW | 0000_0000_0000_0000_1000_0000 | Writes the current value to the BUS |
| ALU_OUT |  Active_LOW | 0000_1000_0000_0000_0000_0000 | Writes the current value to the BUS |
| RST | Active_HIGH | X | Reset the register's value to 0 |
| CLK | Active_HIGH | X | The main clock signal |

### I/O
| Name | Size | Type | Description |
|:---|---:|---:|---:|
| ALU | 8 bits | In | Output of the ALU, before the transceiver |
| BUS | 4 bits | In / Out | Direct connection to the BUS |
| A_8 |  1 bit | In | The 8th bit of the A Register, before the transceiver |
| CARRY  |  1 bit | In | The CARRY flag of the ALU |
| *_F |  4 bit | Out | The 4 least significant bits of the Register |

## Parts list
| Part | Quantity |
|:---|---:|
| Breadboard BB830 | 1 |
| 220Ω Resistor | 4 |
| 0,1µF Capacitor | 4 |
| CD74HCT173E (4 bits Register) | 1 |
| CD74HCT02E (4x 2-NORs) | 1 |
| CD74HCT08E (4x 2-ANDs) | 1 |
| CD74HCT86E (4x 2-XORs) | 1 |
| CD74HCT157E (2 lines to 1 bit Encoder)  | 1 |
| CD74HCT245E (8 bits Bus Transceiver) | 1 |
| Red LED | 4 |

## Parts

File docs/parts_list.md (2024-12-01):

# 8 bits Breadboard Computer - Parts list

Digikey basket export [here](digikey_basket.csv) (This basket have some spare resistors capacitors and LEDs).  **(~375€)**

[This](digikey_basket_with_spare.csv) second basket export has spare for every single component. **(~400€)**

! Part list not up to date, schematics where rewired a bit and some more ICs where needed, refer to each module's part list that are up to date, or take the one with spare components !

| Part | Quantity |
|:---|---:|
| Breadboard BB830 | 20 |
| 220Ω Resistor | 123 |
| 1kΩ Resistor | 10 |
| 100kΩ Resistor | 1 |
| 1MΩ Resistor | 1 |
| 1MΩ Potentiometer | 1 |
| 1nF Capacitor | 1 |
| 0,1µF Capacitor | 62 |
| 0,01µF Capacitor | 6 | 
| 1µF Capacitor | 1 |
| LM555CN (Timer) | 4 |
| CD74HCT00E (4x 2-NANDs) | 4 |
| CD74HCT02E (4x 2-NORs) | 1 |
| CD74HCT04E (8x Inverters) | 4 |
| CD74HCT08E (4x 2-ANDs) | 3 |
| CD74HCT11E (3x 3-NANDs) | 1 |
| CD74HCT32E (2x 4-ORs) | 1 |
| CD74HCT86E  (4x 2-XORs) | 3 |
| CD74HCT107E (Dual JK-Flip-Flops) | 1 |
| CD74HCT139E (2 bits to 4 lines Decoder) | 1 |
| CD74HCT157E (2 lines to 1 bit Encoder)  | 6 |
| CD74HCT161E (4 bits Counter) | 5 |
| CD74HCT173E (4 bits Register) | 15 |
| CD74HCT193E (4 bits UP/DOWN Counter) | 2 |
| CD74HCT245E (8 bits Bus Transceiver) | 13 |
| CD74HCT273E (8x D-Flip-Flops) | 1 |
| CD74HCT283E (4 bits Full Adder) | 2 |
| AT28C64B-15PU | 1 |
| AT28C256-15PU | 3 |
| AS6C1008-55PIN | 1 |
| Yellow LED | 13 |
| Red LED | 100 |
| Green LED | 3 |
| Blue LED | 25 |
| Push Button | 2 |
| Toggle Switch | 3 |
| 8 bits DIP switch | 3 |
| 7 Segments Display | 4 |
| Arduino NANO (EEPROM Programmer) | 1 |
| CD74HCT164E (EEPROM Programmer) | 2 |
| 47µF Capacitor (EEPROM Programmer) | 1 |
| Cable Spools | 1 |
| Wire Stripper | 1 |

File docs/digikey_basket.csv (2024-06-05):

Index | Quantité | Référence | Référence fabricant | Description | Référence client | Disponible | Articles différés | Prix unitaire | Prix calculé EUR
1 | 4 | LM555CNNS/NOPB-ND | LM555CN/NOPB | IC OSC SINGLE TIMER 100KHZ 8-DIP |  | 4 | 0 | 1,21000 | 4,84
2 | 4 | 296-2081-5-ND | CD74HCT00E | IC GATE NAND 4CH 2-INP 14DIP |  | 4 | 0 | 0,56000 | 2,24
3 | 1 | 296-2082-5-ND | CD74HCT02E | IC GATE NOR 4CH 2-INP 14DIP |  | 1 | 0 | 0,56000 | 0,56
4 | 4 | 296-2083-5-ND | CD74HCT04E | IC INVERTER 6CH 1-INP 14DIP |  | 4 | 0 | 0,66000 | 2,64
5 | 3 | 296-2084-5-ND | CD74HCT08E | IC GATE AND 4CH 2-INP 14DIP |  | 3 | 0 | 0,72000 | 2,16
6 | 1 | 296-2112-5-ND | CD74HCT32E | IC GATE OR 4CH 2-INP 14DIP |  | 1 | 0 | 0,72000 | 0,72
7 | 3 | 296-2133-5-ND | CD74HCT86E | IC GATE XOR 4CH 2-INP 14DIP |  | 3 | 0 | 0,80000 | 2,40
8 | 1 | 296-33126-5-ND | CD74HCT107E | IC FF JK TYPE DUAL 1BIT 14DIP |  | 1 | 0 | 0,83000 | 0,83
9 | 1 | 296-2092-5-ND | CD74HCT139E | IC DECODER/DEMUX 1X2:4 16DIP |  | 1 | 0 | 0,80000 | 0,80
10 | 6 | 296-2095-5-ND | CD74HCT157E | IC MULTIPLEXER 4 X 2:1 16DIP |  | 6 | 0 | 0,80000 | 4,80
11 | 5 | 296-2096-5-ND | CD74HCT161E | IC BINARY COUNTER 4-BIT 16DIP |  | 5 | 0 | 0,91000 | 4,55
12 | 15 | 296-33135-5-ND | CD74HCT173E | IC FF D-TYPE SNGL 4BIT 16DIP |  | 15 | 0 | 0,66700 | 10,01
13 | 13 | 296-2105-5-ND | CD74HCT245E | IC TXRX NON-INVERT 5.5V 20DIP |  | 13 | 0 | 0,87000 | 11,31
14 | 1 | 296-2110-5-ND | CD74HCT273E | IC FF D-TYPE SNGL 8BIT 20DIP |  | 1 | 0 | 0,92000 | 0,92
15 | 2 | 296-33143-5-ND | CD74HCT283E | IC BIN FULL 4BIT ADD W/CAR 16DIP |  | 2 | 0 | 0,90000 | 1,80
16 | 1 | AT28C64B-15PU-ND | AT28C64B-15PU | IC EEPROM 64KBIT PARALLEL 28DIP |  | 1 | 0 | 5,23000 | 5,23
17 | 3 | AT28C256-15PU-ND | AT28C256-15PU | IC EEPROM 256KBIT PARALLEL 28DIP |  | 3 | 0 | 11,05000 | 33,15
18 | 1 | 1450-1165-5-ND | AS6C1008-55PIN | IC SRAM 1MBIT PARALLEL 32DIP |  | 1 | 0 | 5,78000 | 5,78
19 | 2 | 296-2097-5-ND | CD74HCT164E | IC 8-BIT SHIFT REGISTER HS 14DIP |  | 2 | 0 | 0,61000 | 1,22
20 | 1 | 399-ESK476M050AE3AA-ND | ESK476M050AE3AA | CAP ALUM 47UF 20% 50V RADIAL |  | 1 | 0 | 0,20000 | 0,20
21 | 1 | 1050-ABX00033-ND | ABX00033 | ARDUINO NANO EVERY WITH HEADERS |  | 1 | 0 | 13,57000 | 13,57
22 | 4 | TDSR1360-IK-ND | TDSR1360-IK | DISPLAY 7SEG 0.51" SGL RED 10DIP |  | 4 | 0 | 1,90000 | 7,60
23 | 3 | EG4499-ND | KAS1108E | SWITCH SLIDE DIP SPST 0.025A 24V |  | 3 | 0 | 1,14000 | 3,42
24 | 3 | 450-1567-ND | 1825255-1 | SWITCH SLIDE SPDT 300MA 125V |  | 3 | 0 | 1,09000 | 3,27
25 | 2 | EG4371-ND | TL1105PF160Q | SWITCH TACTILE SPST-NO 0.05A 12V |  | 2 | 0 | 0,19000 | 0,38
26 | 1 | 56-K105K20X7RF53H5G-ND | K105K20X7RF53H5G | K 50V 1UF 10% X7R BULK GREEN AUT |  | 1 | 0 | 1,90000 | 1,90
27 | 10 | 490-8812-ND | RDER71H103K0K1H03B | CAP CER 10000PF 50V X7R RADIAL |  | 10 | 0 | 0,27900 | 2,79
28 | 100 | 56-K104K15X7RF53H5G-ND | K104K15X7RF53H5G | K 50V 100NF 10% X7R BULK GREEN A |  | 100 | 0 | 0,29700 | 29,70
29 | 1 | 56-K102J15C0GF53H5G-ND | K102J15C0GF53H5G | K 50V 1NF 5% C0G BULK GREEN AUTO |  | 1 | 0 | 0,39000 | 0,39
30 | 1 | 3310C-001-105L-ND | 3310C-001-105L | POT 1M OHM 1/4W PLASTIC LINEAR |  | 1 | 0 | 3,53000 | 3,53
31 | 250 | 13-CFR-25JT-52-220RCT-ND | CFR-25JT-52-220R | RES 220 OHM 5% 1/4W AXIAL |  | 250 | 0 | 0,02004 | 5,01
32 | 25 | 13-CFR-25JT-52-1KCT-ND | CFR-25JT-52-1K | RES 1K OHM 5% 1/4W AXIAL |  | 25 | 0 | 0,04680 | 1,17
33 | 10 | 13-CFR-25JT-52-100KCT-ND | CFR-25JT-52-100K | RES 100K OHM 5% 1/4W AXIAL |  | 10 | 0 | 0,06100 | 0,61
34 | 10 | 13-CFR-25JT-52-1MCT-ND | CFR-25JT-52-1M | RES 1M OHM 5% 1/4W AXIAL |  | 10 | 0 | 0,04300 | 0,43
35 | 20 | 4526-BB830-ND | BB830 | WHITE 830-POINT BREADBOARD, 4 PO |  | 20 | 0 | 7,85000 | 157,00
36 | 100 | 67-1107-ND | SSL-LX5093IT | LED RED CLEAR T-1 3/4 T/H |  | 100 | 0 | 0,17480 | 17,48
37 | 25 | 754-1887-ND | WP7083QBD/G | LED BLUE DIFFUSED T-1 3/4 T/H |  | 25 | 0 | 0,44600 | 11,15
38 | 10 | 754-1731-ND | WP7113GT | LED GREEN CLEAR T-1 3/4 T/H |  | 10 | 0 | 0,16100 | 1,61
39 | 20 | 754-1741-ND | WP7113YT | LED YELLOW CLEAR T-1 3/4 T/H |  | 20 | 0 | 0,22800 | 4,56
40 | 1 | 2882-15DYS818-050300W-2-ND | 15DYS818-050300W-2 | AC/DC WALL MOUNT ADAPTER 5V 15W |  | 1 | 0 | 9,11000 | 9,11
41 | 1 | 296-2087-5-ND | CD74HCT11E | IC GATE AND 3CH 3-INP 14DIP |  | 1 | 0 | 0,83000 | 0,83
42 | 2 | 296-2142-5-ND | CD74HCT193E | IC BINARY COUNTER 4-BIT 16DIP |  | 2 | 0 | 0,94000 | 1,88

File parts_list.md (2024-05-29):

# Parts list :

EEPROM Programmer : https://tomnisbet.github.io/TommyPROM/docs/hardware

| Part | Quantity | Unit Price | Total | Link |
|:---|---:|---:|---:|---:|
| Breadboard BB830 | 16 | 8,12 € | 129,92 € | [Link](https://www.mouser.fr/ProductDetail/BusBoard-Prototype-Systems/BB830?qs=VEfmQw3KOauhPeTwYxNCaA%3D%3D) |
| 1kΩ Resistor | 40 | 0,03 € | 1,36 € | [Link](https://www.mouser.fr/ProductDetail/YAGEO/CFR-25JR-52-1K?qs=sGAEpiMZZMtlubZbdhIBIG2rwDeDG2Hz0nFs2Ia3WF8%3D) |
| 10kΩ Resistor | 40 | 0,05 € | 1,92 € | [Link](https://www.mouser.fr/ProductDetail/YAGEO/CFR25SJT-26-10K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) |
| 100kΩ Resistor | 20 | 0,04 € | 0,72 € | [Link](https://www.mouser.fr/ProductDetail/YAGEO/CFR-25JT-52-100K?qs=sGAEpiMZZMtlubZbdhIBIGhJWRsHPi3Sk4OTVw1zMIc%3D) |
| 220Ω Resistor | 100 | 0,02 € | 2,00 € | [Link](https://www.mouser.fr/ProductDetail/YAGEO/CFR-25JT-52-220R?qs=KUIzHt%2Fe91lrctWTReofaw%3D%3D) |
| 470Ω Resistor | 50 | 0,06 € | 3,00 € | [Link](https://www.mouser.fr/ProductDetail/YAGEO/CFR-25JB-52-470R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) |
| 1MΩ Resistor | 10 | 0,04 € | 0,36 € | [Link](https://www.mouser.fr/ProductDetail/YAGEO/CFR-25JT-52-1M?qs=sGAEpiMZZMtlubZbdhIBIFoOGUvNp40aH4%2FXjzEg6fE%3D) |
| 1MΩ Potentiometer | 1 | 3,48 € | 3,48 € | [Link](https://www.mouser.fr/ProductDetail/Bourns/3310C-001-105L?qs=eLugBjTgzvPv9Y%2FgcMMx5A%3D%3D) |
| 1nF Capacitor | 5 | 0,56 € | 2,79 € | [Link](https://www.mouser.fr/ProductDetail/Vishay-BC-Components/K102J15C0GF53H5G?qs=DPoM0jnrROVTxjmlWxnrvw%3D%3D) |
| 0,01µF Capacitor | 10 | 0,28 € | 2,75 € | [Link](https://www.mouser.fr/ProductDetail/Murata-Electronics/RDER71H103K0K1H03B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) |
| 0,1µF Capacitor | 20 | 0,37 € | 7,36 € | [Link](https://www.mouser.fr/ProductDetail/Vishay-BC-Components/K104K15X7RF53H5G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) |
| 1µF Capacitor | 2 | 1,92 € | 3,84 € | [Link](https://www.mouser.fr/ProductDetail/Vishay-BC-Components/K105K20X7RF53H5G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) |
| LM555CN (Timer) | 4 | 1,21 € | 4,84 € | [Link](https://www.mouser.lu/ProductDetail/Texas-Instruments/LM555CN-NOPB?qs=QbsRYf82W3GjZpQL%2FakZOg%3D%3D) |
| SN74LS00N (4x 2-NANDs) | 4 | 0,61 € | 2,46 € | [Link](https://www.mouser.lu/ProductDetail/Texas-Instruments/SN74LS00N?qs=spW5eSrOWB6G5wECF%252BEZFA%3D%3D) |
| SN74LS02N (4x 2-NORs) | 1 | 0,51 € | 0,51 € | [Link](https://www.mouser.lu/ProductDetail/Texas-Instruments/SN74LS02N?qs=spW5eSrOWB4KM%252BpAgRke5g%3D%3D) |
| SN74LS04N (8x Inverters) | 5 | 0,62 € | 3,12 € | [Link](https://www.mouser.lu/ProductDetail/Texas-Instruments/SN74LS04N?qs=spW5eSrOWB4DgGWIHPxzvg%3D%3D) |
| SN74LS08N (4x 2-ANDs) | 3 | 0,72 € | 2,15 € | [Link](https://www.mouser.lu/ProductDetail/Texas-Instruments/SN74LS08N?qs=spW5eSrOWB4y5MjcKVGhlA%3D%3D) |
| SN74LS32N (2x 4-ORs) | 1 | 0,52 € | 0,52 € | [Link](https://www.mouser.lu/ProductDetail/Texas-Instruments/SN74LS32N?qs=q2XTDbzbm6DA9Mnew5GiLA%3D%3D) |
| SN74LS107AN (Dual JK-Flip-Flops) | 1 | 2,52 € | 2,52 € | [Link](https://www.mouser.lu/ProductDetail/Texas-Instruments/SN74LS107AN?qs=HE9hdJajmepydgZvtE%2FvQg%3D%3D) |
| SN74LS86AN  (4x 2-XORs) | 2 | 0,62 € | 1,25 € | [Link](https://www.mouser.lu/ProductDetail/Texas-Instruments/SN74LS86AN?qs=mTHRaKC2c7P%2FJtp1i2FCFw%3D%3D) |
| SN74LS42N (4 bits to 10 lines Decoder)  | 1 | 3,03 € | 3,03 € | [Link](https://www.mouser.lu/ProductDetail/Texas-Instruments/SN74LS42N?qs=OorDGPQ79EpmRjK3jwIo9A%3D%3D) |
| SN74LS139AN (2 bits to 4 lines Decoder) | 1 | 0,69 € | 0,69 € | [Link](https://www.mouser.lu/ProductDetail/Texas-Instruments/SN74LS139AN?qs=3pnr37ZAbK%2FhW2T3DHZDAw%3D%3D) |
| SN74LS157N (2 lines to 1 bit Encoder) | 4 | 0,82 € | 3,27 € | [Link](https://www.mouser.lu/ProductDetail/Texas-Instruments/SN74LS157N?qs=LzFo6vGRJ4stINDkpW5nIA%3D%3D) |
| SN74LS161AN (4 bits Counter) | 3 | 0,84 € | 2,51 € | [Link](https://www.mouser.lu/ProductDetail/Texas-Instruments/SN74LS161AN?qs=pt%2FIv5r0EPdAOdsihx36Qg%3D%3D) |
| SN74LS173AN (4 bits Register) | 10 | 1,66 € |  16,60 € | [Link](https://www.mouser.lu/ProductDetail/Texas-Instruments/SN74LS173AN?qs=nMmhAzRCgdAkY4Cck6ihbQ%3D%3D) |
| SN74LS245N (8 bits Bus Transceiver) | 6 | 1,15 € | 6,90 € | [Link](https://www.mouser.lu/ProductDetail/Texas-Instruments/SN74LS245N?qs=tJ5HNKWh3OU3CUIGSPX6%2Fg%3D%3D) |
| SN74LS273N (8x D-Flip-Flops) | 1 | 1,20 € | 1,20 € | [Link](https://www.mouser.lu/ProductDetail/Texas-Instruments/SN74LS273N?qs=DcvZ7Fltd5yuwihPzPUL0Q%3D%3D) |
| SN74LS283N (4 bits Full Adder) | 2 | 2,20 € | 4,40 € | [Link](https://www.mouser.lu/ProductDetail/Texas-Instruments/SN74LS283N?qs=RnzODY3cU8uVeiPelRVWjw%3D%3D) |
| Toggle Switch | 3 | 1,09 € | 3,27 € | [Link](https://www.mouser.lu/ProductDetail/TE-Connectivity-Alcoswitch/MHS12204?qs=x%2FgbKjZ2T%2FPUluB%2FWhqq0Q%3D%3D) |
| Push Button | 3 | 0,20 € | 0,59 € | [Link](https://www.mouser.lu/ProductDetail/E-Switch/TL1105PF160Q?qs=iWbXB9lueyCtFh0h%2FBaqIg%3D%3D) |
| 8 bits DIP switch | 2 | 1,64 € | 3,28 € | [Link](https://www.mouser.lu/ProductDetail/E-Switch/KAS1108E?qs=f57gQzlyLiprZHQecsfCqA%3D%3D) |
| Red LED | 50 | 0,12 € | 6,10 € | [Link](https://www.mouser.lu/ProductDetail/Lumex/SSL-LX5093IT?qs=z5hCOXTvo57cxO7p%252BvLJIw%3D%3D) |
| Green LED | 20 | 0,16 € | 3,24 € | [Link](https://www.mouser.lu/ProductDetail/Kingbright/WP7113GT?qs=pz0eHrWKk7l3r4lHAQVJ9A%3D%3D) |
| Blue LED | 30 | 0,40 € |  11,97 € | [Link](https://www.mouser.lu/ProductDetail/Kingbright/WP7083QBD-G?qs=vEWui5pQpatbKK552qzGvw%3D%3D) |
| Yellow LED | 10 | 0,23 € | 2,26 € | [Link](https://www.mouser.lu/ProductDetail/Kingbright/WP7113YT?qs=YPg7lQ8MWSfGn6TgDjFnaQ%3D%3D) |
| EEPROM 32K * 8bit | 2 | 10,81 € |  21,62 € | [Link](https://www.mouser.fr/ProductDetail/Microchip-Technology/AT28C256-15PU?qs=MAR%2F2X5XOp7eAU2%2FlNw9oA%3D%3D) |
| EEPROM 8k * 8 | 1 | 5,12 € | 5,12 € | [Link](https://www.mouser.fr/ProductDetail/Microchip-Technology/AT28C64B-15PU?qs=2VKgqYuc3OvipbcAuBcLow%3D%3D) |
| RAM | 1 | 12,82 € |  12,82 € | [Link](https://www.mouser.fr/ProductDetail/Renesas-Electronics/7130LA35PDG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.) |
| Arduino NANO (EEPROM Programmer) | 1 | 14,22 € |  14,22 € | [Link](https://www.mouser.fr/ProductDetail/Arduino/ABX00033?qs=PzGy0jfpSMueXyfBfl2XSA%3D%3D) |
| CD74HCT164E (EEPROM Programmer) | 2 | 0,61 € | 1,23 € | [Link](https://www.mouser.fr/ProductDetail/Texas-Instruments/CD74HCT164E?qs=6gY4t2uohMwAmwONDb%2FR0A%3D%3D) |
| 47µF Capacitor (EEPROM Programmer) | 1 | 0,21 € | 0,21 € | [Link](https://www.mouser.fr/ProductDetail/KYOCERA-AVX/RES0611470M050B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) |
| Cable Spools | 1 | 20,00 € |  20,00 € | [Link](https://www.amazon.fr/TUOFENG-bobines-diff%C3%A9rente-raccordement-cavalier/dp/B07V5FVSYL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) |
| Wire Stripper | 1 | 13,50 € |  13,50 € | [Link](https://www.amazon.fr/Wirefy-STRP-01-Pince-d%C3%A9nuder-solides/dp/B083LKTZXT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) |

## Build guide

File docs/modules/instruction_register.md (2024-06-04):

# 8 bits Breadboard Computer - Instruction Register

## Diagram


## Description

### Signals
| Signal | Mode | Binary mask | Description |
|:---|---:|:---:|---:|
| IR_IN  |  Active_LOW | 0000_0000_0000_0010_0000_0000 | Will capture the BUS's value at the next @CLK |
| RST | Active_HIGH | X | Reset the register's value to 0 |
| CLK | Active_HIGH | X | The main clock signal |

### I/O
| Name | Size | Type | Description |
|:-----|---:|---:|---:|
| BUS  | 8 bits | In | Direct connection to the BUS |
| IR | 6 bits | Out | Output of the register |

## Parts list
| Part | Quantity |
|:---|---:|
| Breadboard BB830 | 1 |
| 220Ω Resistor | 8 |
| 0,1µF Capacitor | 2 |
| CD74HCT173E (4 bits Register) | 2 |
| Yellow LED | 8 |

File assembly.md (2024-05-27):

## Guidelines

This assembly language has some global restrictions :

- It only supports 8 bits values
- The largest address is 0xFF = 255
- The size after compilation must not exceed 0xFF = 256 bytes

File should start with this header

```
#BB8BC_ASM_v1
```

## Comments

Comments can be added anywhere in the code with the following syntax

```
LDA $FA //load the value at the location $FA into the A Register
```

## Addressing Modes

This assembly language support 2 addressing modes :

- **Direct Addressing** : `LDA FD` This addressing mode will interpret the value as is, being an address or a value depending on the instruction
- **Indirect Addressing** : `LDA $(FD)` This addressing mode will interpret the value as a pointer, and will use the value stored at the address as the argument, for a direct addressing execution

Some instruction can use a 3rd addressing mode, in case they do not take arguments, in that case they will use the value in the A Register

## Instructions

| Instruction | Type | Addressing mode | Opcode | Size (bytes) | Clock cycles | Desc |
|:---|---:|---:|:---:|:---:|:---:|---:|
| <span style="color:#808080;">NOP</span> | <span style="color:#D0F000;">Misc.</span> | None |  0x00  | 1 | 3c | Do nothing |
| LDA FD | <span style="color:#D000D0;">Memory</span> | Direct |  0x01  | 2 | 6c | **Load** the value of the argument into the **A Register** |
| LDA $(FD) | <span style="color:#D000D0;">Memory</span> | Indirect |  0x02  | 2 | 7c | **Load** the value at the address pointed by the argument into the **A Register** |
| <span style="color:#808080;">LDB $FD</span> | <span style="color:#D000D0;">Memory</span> | Direct |  0x03  | 2 | 6c | **Load** the value of the argument into the **B Register** |
| <span style="color:#808080;">LDB $(FD)</span> | <span style="color:#D000D0;">Memory</span> | Indirect |  0x04  | 2 | 7c | **Load** the value at the address pointed by the argument into the **B Register** |
| OUT FD | <span style="color:#D000D0;">Memory</span> | Direct |  0x05  | 2 | 6c | **Put** the value of the argument into the **Output Register** |
| OUT $(FD) | <span style="color:#D000D0;">Memory</span> | Indirect |  0x06  | 2 | 7c | **Put** the value at the address pointed by the argument into the **Output Register** |
| OUT | <span style="color:#D000D0;">Memory</span> | Implied |  0x07  | 1 | 4c | **Put** the value of the **A Register** into the **Output Register** |
| <span style="color:#808080;">STA FD</span> | <span style="color:#D000D0;">Memory</span> | Direct |  0x08  | 2 | 7c | **Store** the value of the **A Register** at the address pointed by the argument |
| <span style="color:#808080;">STA $(FD)</span> | <span style="color:#D000D0;">Memory</span> | Indirect |  0x09  | 2 | 8c | **Store** the value of the **A Register** at the address stored at the address pointed by the argument |
| ADD FD | <span style="color:#00D0D0;">Logic</span> | Direct |  0x0A  | 2 | 7c | **Add** the value of the argument to the **A Register** and **update** the **Status Register** |
| ADD $(FD) | <span style="color:#00D0D0;">Logic</span> | Indirect |  0x0B  | 2 | 8c | **Add** the value at the address pointer by the argument to the **A Register** and **update** the **Status Register** |
| <span style="color:#808080;">SUB FD</span> | <span style="color:#00D0D0;">Logic</span> | Direct |  0x0C  | 2 | 7c | **Subtract** the value of the argument from the **A Register** and **update** the **Status Register** |
| <span style="color:#808080;">SUB $(FD)</span> | <span style="color:#00D0D0;">Logic</span> | Indirect |  0x0D  | 2 | 8c | **Subtract** the value at the address pointer by the argument from the **A Register** and **update** the **Status Register** |
| CMP FD | <span style="color:#00D0D0;">Logic</span> | Direct |  0x0E  | 2 | 7c | **Subtract** the value of the argument from the value of the **A Register** and **update the **Status Register**, **A Register\*\* in unchanged |
| CMP $(FD) | <span style="color:#00D0D0;">Logic</span> | Indirect |  0x0F  | 2 | 8c | **Subtract** the value at the address pointer by the argument from the value of the **A Register** and **update the **Status Register**, **A Register\*\* in unchanged |
| CMP | <span style="color:#00D0D0;">Logic</span> | Implied |  0x10  | 1 | 4c | **Subtract** the value of the **B Register** from the value of the **A Register** and **update the **Status Register**, **A Register\*\* in unchanged |
| <span style="color:#808080;">JMP FD</span> | <span style="color:#E06030;">Branching</span> | Direct |  0x11  | 2 | 6c | **Jump** to the address pointed by the argument |
| <span style="color:#808080;">JMP $(FD)</span> | <span style="color:#E06030;">Branching</span> | Indirect |  0x12  | 2 | 7c | **Jump** to the address stored at the address pointed by the argument |
| JMA | <span style="color:#E06030;">Branching</span> | Implied |  0x13  | 1 | 4c | **Jump** to the address pointed by the value of the **A Register** |
| <span style="color:#808080;">BCS FD</span> | <span style="color:#E06030;">Branching</span> | Direct |  0x14  | 2 | 4-6c | **Jump** to the address pointed by the argument if the **CARRY** Flag is **set** |
| <span style="color:#808080;">BCS $(FD)</span> | <span style="color:#E06030;">Branching</span> | Indirect |  0x15  | 2 | 4-7c | **Jump** to the address stored at the address pointed by the argument if the **CARRY** Flag is **set** |
| BCC FD | <span style="color:#E06030;">Branching</span> | Direct |  0x16  | 2 | 4-6c | **Jump** to the address pointed by the argument if the **CARRY** Flag is **not set** |
| BCC $(FD) | <span style="color:#E06030;">Branching</span> | Indirect |  0x17  | 2 | 4-7c | **Jump** to the address stored at the address pointed by the argument if the **CARRY** Flag is **not set** |
| <span style="color:#808080;">BEQ FD</span> | <span style="color:#E06030;">Branching</span> | Direct |  0x18  | 2 | 4-6c | **Jump** to the address pointed by the argument if the **ZERO** Flag is **set** |
| <span style="color:#808080;">BEQ $(FD)</span> | <span style="color:#E06030;">Branching</span> | Indirect |  0x19  | 2 | 4-7c | **Jump** to the address stored at the address pointed by the argument if the **ZERO** Flag is **set** |
| BNE FD | <span style="color:#E06030;">Branching</span> | Direct |  0x1A  | 2 | 4-6c | **Jump** to the address pointed by the argument if the **ZERO** Flag is **not set** |
| BNE $(FD) | <span style="color:#E06030;">Branching</span> | Indirect |  0x1B  | 2 | 4-7c | **Jump** to the address stored at the address pointed by the argument if the **ZERO** Flag is **not set** |
| <span style="color:#808080;">BMI FD</span> | <span style="color:#E06030;">Branching</span> | Direct |  0x1C  | 2 | 4-6c | **Jump** to the address pointed by the argument if the **NEGATIVE** Flag is **set** |
| <span style="color:#808080;">BMI $(FD)</span> | <span style="color:#E06030;">Branching</span> | Indirect |  0x1D  | 2 | 4-7c | **Jump** to the address stored at the address pointed by the argument if the **NEGATIVE** Flag is **set** |
| BPL FD | <span style="color:#E06030;">Branching</span> | Direct |  0x1E  | 2 | 4-6c | **Jump** to the address pointed by the argument if the **NEGATIVE** Flag is **not set** |
| BPL $(FD) | <span style="color:#E06030;">Branching</span> | Indirect |  0x1F  | 2 | 4-7c | **Jump** to the address stored at the address pointed by the argument if the **NEGATIVE** Flag is **not set** |
| <span style="color:#808080;">BOS FD</span> | <span style="color:#E06030;">Branching</span> | Direct |  0x20  | 2 | 4-6c | **Jump** to the address pointed by the argument if the **OVERFLOW** Flag is **set** |
| <span style="color:#808080;">BOS $(FD)</span> | <span style="color:#E06030;">Branching</span> | Indirect |  0x21  | 2 | 4-7c | **Jump** to the address stored at the address pointed by the argument if the **OVERFLOW** Flag is **set** |
| BOC FD | <span style="color:#E06030;">Branching</span> | Direct |  0x22  | 2 | 4-6c | **Jump** to the address pointed by the argument if the **OVERFLOW** Flag is **not set** |
| BOC $(FD) | <span style="color:#E06030;">Branching</span> | Indirect |  0x23  | 2 | 4-7c | **Jump** to the address stored at the address pointed by the argument if the **OVERFLOW** Flag is **not set** |
| <span style="color:#808080;">HLT</span> | <span style="color:#D0F000;">Misc.</span> | None |  0x3F  | 1 | 3c | Halt execution by cutting the clock |

## Memory Blocks

Memory blocks allows you to declare a static block of memory and fill it with arbitrary data.

A Memory block is defined as follows

```
.block $(addr)
    00 01 02 03 04 05 06 07 08 09 0A 0B 0C 0D 0E 0F
.endblock
```

- Declaration must start with `.block` and specify the base address
- Size is arbitrary but `addr + size` must not exceed 255
- Declaration must end with `.endblock`

## Constants

### Declaration

Constants are the same as a memory block, but only allows for a size of 1 byte

A constant if defined as follows

```
.const name FF
```

- Declaration must start with `.const` followed by an alias
- Aliases must start with a letter, and can contain alphanumeric characters, '-' or '\_'
- Value must be specified as hexadecimal and mandatory

### Usages

Constants have 2 use cases depending on the addressing mode

Assuming the following declaration `.const C 10` we have 2 possible use cases :

- **Direct Addressing** : `ADD _C` this will be compiled as `ADD 10` and add 10 to the A Register
- **Indirect Addressing** : `ADD $_C` this will be compiled as `ADD $(10)` and add the value at address $10 to the A Register

## Variable

### Declaration

Variable allows you to abstract a memory address, it will allocate an available address in the address space and use it as a container

A variable is defined as follows

```
.var name FF
```

- Declaration must start with `.var` followed by an alias
- Aliases must start with a letter, and can contain alphanumeric characters, '-' or '\_'
- Value is specified as Hexadecimal and is optional, if no value is passed it is assumed to be 0

### Usages

Variable have 2 use cases depending on the addressing mode

Assuming the following declaration `.var V FF` with an assigned address of `$F0` we have 2 possible use cases :

- **Direct Addressing** : `STA *V` this will be compiled as `STA F0` and store the content of the A Register at address `F0`
- **Indirect Addressing** : `LDA $V` this will be compiled as `LDA $(F0)` and load value FF into the A Register

## Labels

### Declaration

Labels are just memory address aliases, they are placed one line before an instruction and will reference the address of that instruction
they can then be referenced by branching instructions

A Label is declared as follows

```
:LABEL
```

### Usage

A Label can be referenced by branching instructions as follows

```
:LOOP
    ADD 10
    BCC @LOOP
```

This code will loop until the value in the A Register rolls over 0xFF and sets the Carry Flag,
the `BCC` instruction will jump to the address referenced by the `LOOP` label, which in this case is the `ADD 10` instruction

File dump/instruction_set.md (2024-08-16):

| Hex|  Assembly| Addressing Mode| Size| Clock cycles|
|:-----:|:---|---:|---:|---:|
| 0x00 | NOP  | IMP | 1 | 4c |
| 0x01 | LDA #FD | IMM | 2 | 5c |
| 0x02 | LDA $FD | Z_P | 2 | 8c |
| 0x03 | LDA $00FD | ABS | 3 | 9c |
| 0x04 | LDB #FD | IMM | 2 | 5c |
| 0x05 | LDB $FD | Z_P | 2 | 8c |
| 0x06 | LDB $00FD | ABS | 3 | 9c |
| 0x07 | STA $FD | Z_P | 2 | 8c |
| 0x08 | STA $00FD | ABS | 3 | 9c |
| 0x09 | NOP  | IMP | 1 | 4c |
| 0x0A | NOP  | IMP | 1 | 4c |
| 0x0B | ADD #FD | IMM | 2 | 6c |
| 0x0C | ADD $FD | Z_P | 2 | 9c |
| 0x0D | ADD $00FD | ABS | 3 | 10c |
| 0x0E | ADD $FD, A | IDX | 2 | 9c |
| 0x0F | SUB #FD | IMM | 2 | 6c |
| 0x10 | SUB $FD | Z_P | 2 | 9c |
| 0x11 | SUB $00FD | ABS | 3 | 10c |
| 0x12 | SUB $FD, A | IDX | 2 | 9c |
| 0x13 | NOP  | IMP | 1 | 4c |
| 0x14 | CLS  | IMP | 1 | 3c |
| 0x15 | CMP  | IMP | 1 | 3c |
| 0x16 | CMP #FD | IMM | 2 | 6c |
| 0x17 | CMP $FD | Z_P | 2 | 9c |
| 0x18 | CMP $00FD | ABS | 3 | 10c |
| 0x19 | PHA  | IMP | 1 | 4c |
| 0x1A | NOP  | IMP | 1 | 4c |
| 0x1B | PHS  | IMP | 1 | 4c |
| 0x1C | PLA  | IMP | 1 | 5c |
| 0x1D | PLB  | IMP | 1 | 5c |
| 0x1E | PLS  | IMP | 1 | 5c |
| 0x1F | NOP  | IMP | 1 | 4c |
| 0x20 | JSR $00FD | ABS | 3 | 11c |
| 0x21 | RTS  | IMP | 1 | 12c |
| 0x22 | JMP $FD | Z_P | 2 | 7c |
| 0x23 | JMP $00FD | ABS | 3 | 8c |
| 0x24 | JMP $FD, A | IDX | 2 | 7c |
| 0x25 | BCS $FD | Z_P | 2 | 4-7c |
| 0x26 | BCS $00FD | ABS | 3 | 5-8c |
| 0x27 | BCS $FD, A | IDX | 2 | 4-7c |
| 0x28 | BCC $FD | Z_P | 2 | 4-7c |
| 0x29 | BCC $00FD | ABS | 3 | 5-8c |
| 0x2A | BCC $FD, A | IDX | 2 | 4-7c |
| 0x2B | BNE $FD | Z_P | 2 | 4-7c |
| 0x2C | BNE $00FD | ABS | 3 | 5-8c |
| 0x2D | BNE $FD, A | IDX | 2 | 4-7c |
| 0x2E | BEQ $FD | Z_P | 2 | 4-7c |
| 0x2F | BEQ $00FD | ABS | 3 | 5-8c |
| 0x30 | BEQ $FD, A | IDX | 2 | 4-7c |
| 0x31 | BPL $FD | Z_P | 2 | 4-7c |
| 0x32 | BPL $00FD | ABS | 3 | 5-8c |
| 0x33 | BPL $FD, A | IDX | 2 | 4-7c |
| 0x34 | BMI $FD | Z_P | 2 | 4-7c |
| 0x35 | BMI $00FD | ABS | 3 | 5-8c |
| 0x36 | BMI $FD, A | IDX | 2 | 4-7c |
| 0x37 | BOC $FD | Z_P | 2 | 4-7c |
| 0x38 | BOC $00FD | ABS | 3 | 5-8c |
| 0x39 | BOC $FD, A | IDX | 2 | 4-7c |
| 0x3A | BOS $FD | Z_P | 2 | 4-7c |
| 0x3B | BOS $00FD | ABS | 3 | 5-8c |
| 0x3C | BOS $FD, A | IDX | 2 | 4-7c |
| 0x3D | NOP  | IMP | 1 | 4c |
| 0x3E | NOP  | IMP | 1 | 4c |
| 0x3F | HLT  | IMP | 1 | 4c |
| 0x40 | NOP  | IMP | 1 | 4c |
| 0x41 | NOP  | IMP | 1 | 4c |
| 0x42 | NOP  | IMP | 1 | 4c |
| 0x43 | NOP  | IMP | 1 | 4c |
| 0x44 | NOP  | IMP | 1 | 4c |
| 0x45 | NOP  | IMP | 1 | 4c |
| 0x46 | NOP  | IMP | 1 | 4c |
| 0x47 | NOP  | IMP | 1 | 4c |
| 0x48 | NOP  | IMP | 1 | 4c |
| 0x49 | NOP  | IMP | 1 | 4c |
| 0x4A | NOP  | IMP | 1 | 4c |
| 0x4B | NOP  | IMP | 1 | 4c |
| 0x4C | NOP  | IMP | 1 | 4c |
| 0x4D | NOP  | IMP | 1 | 4c |
| 0x4E | NOP  | IMP | 1 | 4c |
| 0x4F | NOP  | IMP | 1 | 4c |
| 0x50 | NOP  | IMP | 1 | 4c |
| 0x51 | NOP  | IMP | 1 | 4c |
| 0x52 | NOP  | IMP | 1 | 4c |
| 0x53 | NOP  | IMP | 1 | 4c |
| 0x54 | NOP  | IMP | 1 | 4c |
| 0x55 | NOP  | IMP | 1 | 4c |
| 0x56 | NOP  | IMP | 1 | 4c |
| 0x57 | NOP  | IMP | 1 | 4c |
| 0x58 | NOP  | IMP | 1 | 4c |
| 0x59 | NOP  | IMP | 1 | 4c |
| 0x5A | NOP  | IMP | 1 | 4c |
| 0x5B | NOP  | IMP | 1 | 4c |
| 0x5C | NOP  | IMP | 1 | 4c |
| 0x5D | NOP  | IMP | 1 | 4c |
| 0x5E | NOP  | IMP | 1 | 4c |
| 0x5F | NOP  | IMP | 1 | 4c |
| 0x60 | NOP  | IMP | 1 | 4c |
| 0x61 | NOP  | IMP | 1 | 4c |
| 0x62 | NOP  | IMP | 1 | 4c |
| 0x63 | NOP  | IMP | 1 | 4c |
| 0x64 | NOP  | IMP | 1 | 4c |
| 0x65 | NOP  | IMP | 1 | 4c |
| 0x66 | NOP  | IMP | 1 | 4c |
| 0x67 | NOP  | IMP | 1 | 4c |
| 0x68 | NOP  | IMP | 1 | 4c |
| 0x69 | NOP  | IMP | 1 | 4c |
| 0x6A | NOP  | IMP | 1 | 4c |
| 0x6B | NOP  | IMP | 1 | 4c |
| 0x6C | NOP  | IMP | 1 | 4c |
| 0x6D | NOP  | IMP | 1 | 4c |
| 0x6E | NOP  | IMP | 1 | 4c |
| 0x6F | NOP  | IMP | 1 | 4c |
| 0x70 | NOP  | IMP | 1 | 4c |
| 0x71 | NOP  | IMP | 1 | 4c |
| 0x72 | NOP  | IMP | 1 | 4c |
| 0x73 | NOP  | IMP | 1 | 4c |
| 0x74 | NOP  | IMP | 1 | 4c |
| 0x75 | NOP  | IMP | 1 | 4c |
| 0x76 | NOP  | IMP | 1 | 4c |
| 0x77 | NOP  | IMP | 1 | 4c |
| 0x78 | NOP  | IMP | 1 | 4c |
| 0x79 | NOP  | IMP | 1 | 4c |
| 0x7A | NOP  | IMP | 1 | 4c |
| 0x7B | NOP  | IMP | 1 | 4c |
| 0x7C | NOP  | IMP | 1 | 4c |
| 0x7D | NOP  | IMP | 1 | 4c |
| 0x7E | NOP  | IMP | 1 | 4c |
| 0x7F | NOP  | IMP | 1 | 4c |
| 0x80 | NOP  | IMP | 1 | 4c |
| 0x81 | NOP  | IMP | 1 | 4c |
| 0x82 | NOP  | IMP | 1 | 4c |
| 0x83 | NOP  | IMP | 1 | 4c |
| 0x84 | NOP  | IMP | 1 | 4c |
| 0x85 | NOP  | IMP | 1 | 4c |
| 0x86 | NOP  | IMP | 1 | 4c |
| 0x87 | NOP  | IMP | 1 | 4c |
| 0x88 | NOP  | IMP | 1 | 4c |
| 0x89 | NOP  | IMP | 1 | 4c |
| 0x8A | NOP  | IMP | 1 | 4c |
| 0x8B | NOP  | IMP | 1 | 4c |
| 0x8C | NOP  | IMP | 1 | 4c |
| 0x8D | NOP  | IMP | 1 | 4c |
| 0x8E | NOP  | IMP | 1 | 4c |
| 0x8F | NOP  | IMP | 1 | 4c |
| 0x90 | NOP  | IMP | 1 | 4c |
| 0x91 | NOP  | IMP | 1 | 4c |
| 0x92 | NOP  | IMP | 1 | 4c |
| 0x93 | NOP  | IMP | 1 | 4c |
| 0x94 | NOP  | IMP | 1 | 4c |
| 0x95 | NOP  | IMP | 1 | 4c |
| 0x96 | NOP  | IMP | 1 | 4c |
| 0x97 | NOP  | IMP | 1 | 4c |
| 0x98 | NOP  | IMP | 1 | 4c |
| 0x99 | NOP  | IMP | 1 | 4c |
| 0x9A | NOP  | IMP | 1 | 4c |
| 0x9B | NOP  | IMP | 1 | 4c |
| 0x9C | NOP  | IMP | 1 | 4c |
| 0x9D | NOP  | IMP | 1 | 4c |
| 0x9E | NOP  | IMP | 1 | 4c |
| 0x9F | NOP  | IMP | 1 | 4c |
| 0xA0 | NOP  | IMP | 1 | 4c |
| 0xA1 | NOP  | IMP | 1 | 4c |
| 0xA2 | NOP  | IMP | 1 | 4c |
| 0xA3 | NOP  | IMP | 1 | 4c |
| 0xA4 | NOP  | IMP | 1 | 4c |
| 0xA5 | NOP  | IMP | 1 | 4c |
| 0xA6 | NOP  | IMP | 1 | 4c |
| 0xA7 | NOP  | IMP | 1 | 4c |
| 0xA8 | NOP  | IMP | 1 | 4c |
| 0xA9 | NOP  | IMP | 1 | 4c |
| 0xAA | NOP  | IMP | 1 | 4c |
| 0xAB | NOP  | IMP | 1 | 4c |
| 0xAC | NOP  | IMP | 1 | 4c |
| 0xAD | NOP  | IMP | 1 | 4c |
| 0xAE | NOP  | IMP | 1 | 4c |
| 0xAF | NOP  | IMP | 1 | 4c |
| 0xB0 | NOP  | IMP | 1 | 4c |
| 0xB1 | NOP  | IMP | 1 | 4c |
| 0xB2 | NOP  | IMP | 1 | 4c |
| 0xB3 | NOP  | IMP | 1 | 4c |
| 0xB4 | NOP  | IMP | 1 | 4c |
| 0xB5 | NOP  | IMP | 1 | 4c |
| 0xB6 | NOP  | IMP | 1 | 4c |
| 0xB7 | NOP  | IMP | 1 | 4c |
| 0xB8 | NOP  | IMP | 1 | 4c |
| 0xB9 | NOP  | IMP | 1 | 4c |
| 0xBA | NOP  | IMP | 1 | 4c |
| 0xBB | NOP  | IMP | 1 | 4c |
| 0xBC | NOP  | IMP | 1 | 4c |
| 0xBD | NOP  | IMP | 1 | 4c |
| 0xBE | NOP  | IMP | 1 | 4c |
| 0xBF | NOP  | IMP | 1 | 4c |
| 0xC0 | NOP  | IMP | 1 | 4c |
| 0xC1 | NOP  | IMP | 1 | 4c |
| 0xC2 | NOP  | IMP | 1 | 4c |
| 0xC3 | NOP  | IMP | 1 | 4c |
| 0xC4 | NOP  | IMP | 1 | 4c |
| 0xC5 | NOP  | IMP | 1 | 4c |
| 0xC6 | NOP  | IMP | 1 | 4c |
| 0xC7 | NOP  | IMP | 1 | 4c |
| 0xC8 | NOP  | IMP | 1 | 4c |
| 0xC9 | NOP  | IMP | 1 | 4c |
| 0xCA | NOP  | IMP | 1 | 4c |
| 0xCB | NOP  | IMP | 1 | 4c |
| 0xCC | NOP  | IMP | 1 | 4c |
| 0xCD | NOP  | IMP | 1 | 4c |
| 0xCE | NOP  | IMP | 1 | 4c |
| 0xCF | NOP  | IMP | 1 | 4c |
| 0xD0 | NOP  | IMP | 1 | 4c |
| 0xD1 | NOP  | IMP | 1 | 4c |
| 0xD2 | NOP  | IMP | 1 | 4c |
| 0xD3 | NOP  | IMP | 1 | 4c |
| 0xD4 | NOP  | IMP | 1 | 4c |
| 0xD5 | NOP  | IMP | 1 | 4c |
| 0xD6 | NOP  | IMP | 1 | 4c |
| 0xD7 | NOP  | IMP | 1 | 4c |
| 0xD8 | NOP  | IMP | 1 | 4c |
| 0xD9 | NOP  | IMP | 1 | 4c |
| 0xDA | NOP  | IMP | 1 | 4c |
| 0xDB | NOP  | IMP | 1 | 4c |
| 0xDC | NOP  | IMP | 1 | 4c |
| 0xDD | NOP  | IMP | 1 | 4c |
| 0xDE | NOP  | IMP | 1 | 4c |
| 0xDF | NOP  | IMP | 1 | 4c |
| 0xE0 | NOP  | IMP | 1 | 4c |
| 0xE1 | NOP  | IMP | 1 | 4c |
| 0xE2 | NOP  | IMP | 1 | 4c |
| 0xE3 | NOP  | IMP | 1 | 4c |
| 0xE4 | NOP  | IMP | 1 | 4c |
| 0xE5 | NOP  | IMP | 1 | 4c |
| 0xE6 | NOP  | IMP | 1 | 4c |
| 0xE7 | NOP  | IMP | 1 | 4c |
| 0xE8 | NOP  | IMP | 1 | 4c |
| 0xE9 | NOP  | IMP | 1 | 4c |
| 0xEA | NOP  | IMP | 1 | 4c |
| 0xEB | NOP  | IMP | 1 | 4c |
| 0xEC | NOP  | IMP | 1 | 4c |
| 0xED | NOP  | IMP | 1 | 4c |
| 0xEE | NOP  | IMP | 1 | 4c |
| 0xEF | NOP  | IMP | 1 | 4c |
| 0xF0 | NOP  | IMP | 1 | 4c |
| 0xF1 | NOP  | IMP | 1 | 4c |
| 0xF2 | NOP  | IMP | 1 | 4c |
| 0xF3 | NOP  | IMP | 1 | 4c |
| 0xF4 | NOP  | IMP | 1 | 4c |
| 0xF5 | NOP  | IMP | 1 | 4c |
| 0xF6 | NOP  | IMP | 1 | 4c |
| 0xF7 | NOP  | IMP | 1 | 4c |
| 0xF8 | NOP  | IMP | 1 | 4c |
| 0xF9 | NOP  | IMP | 1 | 4c |
| 0xFA | NOP  | IMP | 1 | 4c |
| 0xFB | NOP  | IMP | 1 | 4c |
| 0xFC | NOP  | IMP | 1 | 4c |
| 0xFD | NOP  | IMP | 1 | 4c |
| 0xFE | NOP  | IMP | 1 | 4c |
| 0xFF | NOP  | IMP | 1 | 4c |

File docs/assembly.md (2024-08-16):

# 8 bits Breadboard Computer - Assembly Language

## Guidelines

This assembly language has some global restrictions :

- Values are 1 byte.
- Addresses are 2 bytes.
- Address space can go up to $FFFF
- The address space is 1KByte but the last page ($FF00 to $FFFF) is reserved to the stack.
- Stack overflow will trigger the computer to HALT.
- The base computer is designed to work with big endian values.

File should start with this header :

```
#BB8BC_ASM_v1
```

## Comments

Comments can be added anywhere in the code with the following syntax :

```
// Full comment
LDA #10    // Inline comment
```

## Addressing Modes

This assembly is specifically designed to work with the Breadboard computer, therefore it includes all the addressing modes that the hardware implements :
### Implied
**Instructions** using this addressing mode will be **1 byte long** and have **no operand**, the instruction is enough to deduce everything needed for the execution.

Examples :
```
NOP
PHA
PLB
CLS
```

### Immediate
**Instructions** using this addressing mode will be **2 byte long** and have **1 operand**, the operand is interpreted as a **plain hexadecimal value**.

This addressing mode is compatible with **1 byte Constants**.

Operands should be formatted as follows :
- Start with a ``#``.
- **Constants** should be surrounded by parenthesis.

Examples :
```
LDA #FF
STA #(CONST8)
```

### Absolute
This addressing mode works as an absolute pointer.

**Instructions** using this addressing mode will be **3 byte long** and have **2 operands**, the operand is interpreted as a big endian **2 bytes address**.

This addressing mode is compatible with **Variables** and **1 & 2 bytes Constants**, **1 byte Constants** should be completed by a memory page or an offset, if only a 1 byte constant is passed, the compiler will replace it with the **Zero Page** version as it is faster to execute.

Operands should be formatted as follows :
- Start with a ``$`` for plain **address** and **Constants**.
- **Constants** should be surrounded by parenthesis.
- **Variable** should not be prefixed or surrounded.

Examples :
```
LDA $(CONST16)
ADD $2FF
STA VARIABLE
ADD $02(CONST8)
ADD $(CONST8)A9
```

### Zero Page
This addressing mode works in the same way as the **Absolute** mode but is restricted to the first 256 bytes page of memory, and is 1 cycle faster to execute.

**Instructions** using this addressing mode will be **2 byte long** and have **1 operand**, the operand is interpreted as an offset in the 0th memory page.

This addressing mode is compatible with **1 byte Constants**

Operands should be formatted as follows :
- Start with a ``$``
- **Constants** should be surrounded by parenthesis

Examples :
```
LDA $(CONST8)
ADD $80
```

### Indexed
This addressing mode is kind of an extension of **Zero Page** and **Absolute** as it allows to index a **specified memory page** using the **A Register**.

**Instructions** using this addressing mode will be **2 byte long** and have **1 operand**, **the operand** is interpreted the **page to index** (the 8 MSB of the address), **the offset** inside the page is retrieved from the **A Register** 

This addressing mode is compatible with **1 byte Constants**

Operands should be formatted as follows :
- Start with a ``$``
- End with ``, A``
- **Constants** should be surrounded by parenthesis

Examples :
```
ADD $02, A
ADD $(CONST8), A
```

## Instructions

|  Hex  | Assembly | Addressing Mode | Type | Size | Clock cycles |
|:-----:|:---|---:|---:|-----:|---:|
| 0x00  | **[NOP](#nop)** | Implied | Misc. | 1 | 4c | 
| 0x01  | **[LDA](#lda)** <span style="color:#E6DC31;">#FD</span> | <span style="color:#E6DC31;">Immediate</span> | Memory | 2 | 5c | 
| 0x02  | **[LDA](#lda)** <span style="color:#18E637;">$FD</span> | <span style="color:#18E637;">Zero Page</span> | Memory | 2 | 8c | 
| 0x03  | **[LDA](#lda)** <span style="color:#EB412C;">$02FD</span>  |  <span style="color:#EB412C;">Absolute</span> | Memory | 3 | 9c | 
| 0x04  | **[LDB](#ldb)** <span style="color:#E6DC31;">#FD</span> | <span style="color:#E6DC31;">Immediate</span> | Memory | 2 | 5c | 
| 0x05  | **[LDB](#ldb)** <span style="color:#18E637;">$FD</span> | <span style="color:#18E637;">Zero Page</span> | Memory | 2 | 8c | 
| 0x06  | **[LDB](#ldb)** <span style="color:#EB412C;">$02FD</span>  |  <span style="color:#EB412C;">Absolute</span> | Memory | 3 | 9c | 
| 0x07  | **[STA](#sta)** <span style="color:#18E637;">$FD</span> | <span style="color:#18E637;">Zero Page</span> | Memory | 2 | 8c | 
| 0x08  | **[STA](#sta)** <span style="color:#EB412C;">$02FD</span>  |  <span style="color:#EB412C;">Absolute</span> | Memory | 3 | 9c | 
| 0x09  | **[NOP](#nop)** | Implied | Misc. | 1 | 4c | 
| 0x0A  | **[NOP](#nop)** | Implied | Misc. | 1 | 4c | 
| 0x0B  | **[ADD](#add)** <span style="color:#E6DC31;">#FD</span> | <span style="color:#E6DC31;">Immediate</span> | Logic | 2 | 6c | 
| 0x0C  | **[ADD](#add)** <span style="color:#18E637;">$FD</span> | <span style="color:#18E637;">Zero Page</span> | Logic | 2 | 9c | 
| 0x0D  | **[ADD](#add)** <span style="color:#EB412C;">$02FD</span>  |  <span style="color:#EB412C;">Absolute</span> | Logic | 3 | 10c | 
| 0x0E  | **[ADD](#add)** <span style="color:#0797EB;">$FD, A</span> | <span style="color:#0797EB;">Indexed</span> | Logic | 2 | 9c | 
| 0x0F  | **[SUB](#sub)** <span style="color:#E6DC31;">#FD</span> | <span style="color:#E6DC31;">Immediate</span> | Logic | 2 | 6c | 
| 0x10  | **[SUB](#sub)** <span style="color:#18E637;">$FD</span> | <span style="color:#18E637;">Zero Page</span> | Logic | 2 | 9c | 
| 0x11  | **[SUB](#sub)** <span style="color:#EB412C;">$02FD</span>  |  <span style="color:#EB412C;">Absolute</span> | Logic | 3 | 10c | 
| 0x12  | **[SUB](#sub)** <span style="color:#0797EB;">$FD, A</span> | <span style="color:#0797EB;">Indexed</span> | Logic | 2 | 9c | 
| 0x13  | **[NOP](#nop)** | Implied | Misc. | 1 | 4c | 
| 0x14  | **[CLS](#cls)** | Implied | Logic | 1 | 3c | 
| 0x15  | **[CMP](#cmp)** | Implied | Logic | 1 | 3c | 
| 0x16  | **[CMP](#cmp)** <span style="color:#E6DC31;">#FD</span> | <span style="color:#E6DC31;">Immediate</span> | Logic | 2 | 6c | 
| 0x17  | **[CMP](#cmp)** <span style="color:#18E637;">$FD</span> | <span style="color:#18E637;">Zero Page</span> | Logic | 2 | 9c | 
| 0x18  | **[CMP](#cmp)** <span style="color:#EB412C;">$02FD</span>  |  <span style="color:#EB412C;">Absolute</span> | Logic | 3 | 10c | 
| 0x19  | **[PHA](#pha)** | Implied | Memory | 1 | 4c | 
| 0x1A  | **[NOP](#nop)** | Implied | Misc. | 1 | 4c | 
| 0x1B  | **[PHS](#phs)** | Implied | Memory | 1 | 4c | 
| 0x1C  | **[PLA](#pla)** | Implied | Memory | 1 | 5c | 
| 0x1D  | **[PLB](#plb)** | Implied | Memory | 1 | 5c | 
| 0x1E  | **[PLS](#pls)** | Implied | Logic | 1 | 5c | 
| 0x1F  | **[NOP](#nop)** | Implied | Misc. | 1 | 4c | 
| 0x20  | **[JSR](#jsr)** <span style="color:#EB412C;">$02FD</span>  |  <span style="color:#EB412C;">Absolute</span> | Branching | 3 | 11c | 
| 0x21  | **[RTS](#rts)** | Implied | Branching | 1 | 12c | 
| 0x22  | **[JMP](#jpm)** <span style="color:#18E637;">$FD</span> | <span style="color:#18E637;">Zero Page</span> | Branching | 2 | 7c | 
| 0x23  | **[JMP](#jmp)** <span style="color:#EB412C;">$02FD</span>  |  <span style="color:#EB412C;">Absolute</span> | Branching | 3 | 8c | 
| 0x24  | **[JMP](#jmp)** <span style="color:#0797EB;">$FD, A</span> | <span style="color:#0797EB;">Indexed</span> | Branching | 2 | 7c | 
| 0x25  | **[BCS](#bcs)** <span style="color:#18E637;">$FD</span> | <span style="color:#18E637;">Zero Page</span> | Branching | 2 | 4-7c | 
| 0x26  | **[BCS](#bcs)** <span style="color:#EB412C;">$02FD</span>  |  <span style="color:#EB412C;">Absolute</span> | Branching | 3 | 5-8c | 
| 0x27  | **[BCS](#bcs)** <span style="color:#0797EB;">$FD, A</span> | <span style="color:#0797EB;">Indexed</span> | Branching | 2 | 4-7c | 
| 0x28  | **[BCC](#bcc)** <span style="color:#18E637;">$FD</span> | <span style="color:#18E637;">Zero Page</span> | Branching | 2 | 4-7c | 
| 0x29  | **[BCC](#bcc)** <span style="color:#EB412C;">$02FD</span>  |  <span style="color:#EB412C;">Absolute</span> | Branching | 3 | 5-8c | 
| 0x2A  | **[BCC](#bcc)** <span style="color:#0797EB;">$FD, A</span> | <span style="color:#0797EB;">Indexed</span> | Branching | 2 | 4-7c | 
| 0x2B  | **[BNE](#bne)** <span style="color:#18E637;">$FD</span> | <span style="color:#18E637;">Zero Page</span> | Branching | 2 | 4-7c | 
| 0x2C  | **[BNE](#bne)** <span style="color:#EB412C;">$02FD</span>  |  <span style="color:#EB412C;">Absolute</span> | Branching | 3 | 5-8c | 
| 0x2D  | **[BNE](#bne)** <span style="color:#0797EB;">$FD, A</span> | <span style="color:#0797EB;">Indexed</span> | Branching | 2 | 4-7c | 
| 0x2E  | **[BEQ](#beq)** <span style="color:#18E637;">$FD</span> | <span style="color:#18E637;">Zero Page</span> | Branching | 2 | 4-7c | 
| 0x2F  | **[BEQ](#beq)** <span style="color:#EB412C;">$02FD</span>  |  <span style="color:#EB412C;">Absolute</span> | Branching | 3 | 5-8c | 
| 0x30  | **[BEQ](#beq)** <span style="color:#0797EB;">$FD, A</span> | <span style="color:#0797EB;">Indexed</span> | Branching | 2 | 4-7c | 
| 0x31  | **[BPL](#bpl)** <span style="color:#18E637;">$FD</span> | <span style="color:#18E637;">Zero Page</span> | Branching | 2 | 4-7c | 
| 0x32  | **[BPL](#bpl)** <span style="color:#EB412C;">$02FD</span>  |  <span style="color:#EB412C;">Absolute</span> | Branching | 3 | 5-8c | 
| 0x33  | **[BPL](#bpl)** <span style="color:#0797EB;">$FD, A</span> | <span style="color:#0797EB;">Indexed</span> | Branching | 2 | 4-7c | 
| 0x34  | **[BMI](#bmi)** <span style="color:#18E637;">$FD</span> | <span style="color:#18E637;">Zero Page</span> | Branching | 2 | 4-7c | 
| 0x35  | **[BMI](#bmi)** <span style="color:#EB412C;">$02FD</span>  |  <span style="color:#EB412C;">Absolute</span> | Branching | 3 | 5-8c | 
| 0x36  | **[BMI](#bmi)** <span style="color:#0797EB;">$FD, A</span> | <span style="color:#0797EB;">Indexed</span> | Branching | 2 | 4-7c | 
| 0x37  | **[BOC](#boc)** <span style="color:#18E637;">$FD</span> | <span style="color:#18E637;">Zero Page</span> | Branching | 2 | 4-7c | 
| 0x38  | **[BOC](#boc)** <span style="color:#EB412C;">$02FD</span>  |  <span style="color:#EB412C;">Absolute</span> | Branching | 3 | 5-8c | 
| 0x39  | **[BOC](#boc)** <span style="color:#0797EB;">$FD, A</span> | <span style="color:#0797EB;">Indexed</span> | Branching | 2 | 4-7c | 
| 0x3A  | **[BOS](#bos)** <span style="color:#18E637;">$FD</span> | <span style="color:#18E637;">Zero Page</span> | Branching | 2 | 4-7c | 
| 0x3B  | **[BOS](#bos)** <span style="color:#EB412C;">$02FD</span>  |  <span style="color:#EB412C;">Absolute</span> | Branching | 3 | 5-8c | 
| 0x3C  | **[BOS](#bos)** <span style="color:#0797EB;">$FD, A</span> | <span style="color:#0797EB;">Indexed</span> | Branching | 2 | 4-7c | 
| 0x3D  | **[NOP](#nop)** | Implied | Misc. | 1 | 4c | 
| 0x3E  | **[NOP](#nop)** | Implied | Misc. | 1 | 4c | 
| 0x3F  | **[HLT](#hlt)** | Implied | Misc. | 1 | 4c | 

### NOP
Does nothing and passes to the next instruction.

### LDA
Loads a value into the **A Register** from operand or memory depending on [Addressing Mode](#addressing-modes).

### LDB
Loads a value into the **B Register** from operand or memory depending on [Addressing Mode](#addressing-modes).

### STA
Stores the value of the **A Register** in memory

### ADD
Adds a value to the **A Register**, value is determined from the operand depending on [Addressing Mode](#addressing-modes).

Will override the **B Register** with the resolved value to add.

Will update the **Status Register** :
- O : A_8 ^ R_8
- Z : R == 0
- C : R_9 == 1
- N : R_8 == 1

### SUB
Subtracts a value from the **A Register**, value is determined from the operand depending on [Addressing Mode](#addressing-modes).

Will override the **B Register** with the resolved value to subtract.

Will update the **Status Register** :
- O : A_8 ^ R_8
- Z : R == 0
- C : R_9 == 1
- N : R_8 == 1

### CLS
Clears the **Status Register**

### CMP
Compares 2 values, the **A Register** and an operand determined by the [Addressing Mode](#addressing-modes).

Will update the **Status Register** but not the **A Register** :
- O : A_8 ^ R_8
- Z : R == 0
- C : R_9 == 1
- N : R_8 == 1

### PHA
Pushes the content of the **A Register** into the stack.

The stack pointer will be automatically updated.

### PHS
Pushes the content of the **Status Register** into the stack.

The **Stack Pointer** will be automatically updated.

### PLA
Pulls the most recent element from the stack and stores it in to **A Register**

The **Stack Pointer** will be automatically updated.

### PLB
Pulls the most recent element from the stack and stores it in to **B Register**

The **Stack Pointer** will be automatically updated.

### PLS
Pulls the most recent element from the stack and stores it in to **Status Register**

The **Stack Pointer** will be automatically updated.

### JSR
Jumps to a subroutine, and pushes the return address into the stack.

Will take 2 bytes on the stack.

The **Stack Pointer** will be automatically updated.

### RTS
Returns from a subroutine, by pulling the return address into the stack.

Execution will resume at the instruction right after the last ``JSR`` instruction

The **Stack Pointer** will be automatically updated.

### JMP
Jumps to a specified address, determined by the [Addressing Mode](#addressing-modes).

### BCC
Jumps to a specified address, determined by the [Addressing Mode](#addressing-modes) if the **Status Register** has the ``Carry Flag`` cleared : ``Status & 0b0010 == 0b0000``

### BCS
Jumps to a specified address, determined by the [Addressing Mode](#addressing-modes) if the **Status Register** has the ``Carry Flag`` set : ``Status & 0b0010 == 0b0010``

### BNE
Jumps to a specified address, determined by the [Addressing Mode](#addressing-modes) if the **Status Register** has the ``Zero Flag`` cleared : ``Status & 0b0100 == 0b0001``

### BEQ
Jumps to a specified address, determined by the [Addressing Mode](#addressing-modes) if the **Status Register** has the ``Zero Flag`` set : ``Status & 0b0100 == 0b0100``

### BPL
Jumps to a specified address, determined by the [Addressing Mode](#addressing-modes) if the **Status Register** has the ``Negative Flag`` cleared : ``Status & 0b0001 == 0b0000``

### BMI
Jumps to a specified address, determined by the [Addressing Mode](#addressing-modes) if the **Status Register** has the ``Negative Flag`` set : ``Status & 0b0001 == 0b0001``

### BOC
Jumps to a specified address, determined by the [Addressing Mode](#addressing-modes) if the **Status Register** has the ``Overflow Flag`` cleared : ``Status & 0b1000 == 0b0000``

### BOS
Jumps to a specified address, determined by the [Addressing Mode](#addressing-modes) if the **Status Register** has the ``Overflow Flag`` set : ``Status & 0b1000 == 0b1000``

### HLT
Halts the **Clock** until reset

## Memory Blocks

Memory blocks allows you to declare a static block of memory and fill it with arbitrary data.

A Memory block is defined as follows

```
.block $(addr)
    00 01 02 03 04 05 06 07 08 09 0A 0B 0C 0D 0E 0F
.endblock
```

- Declaration must start with `.block` and specify the base address
- Size is arbitrary but `addr + size` should not exceed #FFFF, in practice higher memory address are allowed, but mirroring will be applied
- A Memory Block can not be mapped to reserved addresses, which are **$0000** and **$0001** that are the **entrypoint of execution**, and **$FF00 to $FFFF** which is reserved for the **Stack**
- Declaration must end with `.endblock`

## Constants

### Declaration

Constants are the same as a memory block, but only allows for a size of 1 or 2 bytes

A constant if defined as follows

```
.const byte name #FF
.const word name #FFFF
```

Legal types are ``byte`` for 8 bits Constants and ``word`` for 16 bits Constants

- Declaration must start with `.const` followed a type and an alias
- Aliases must start with a letter, and can contain alphanumeric characters, '-' or '\_'
- Value must be specified as hexadecimal and is mandatory

### Usages

See [Addressing Mode](#addressing-modes) examples

## Variable

### Declaration

Variable allows you to abstract a memory address, it will allocate an available address in the address space and use it as a container

A variable is defined as follows

```
.var name #FF
```

- Declaration must start with `.var` followed by an alias
- Aliases must start with a letter, and can contain alphanumeric characters, '-' or '\_'
- Value is specified as Hexadecimal and is optional, if no value is passed it is assumed to be 0

### Usages

See [Addressing Mode](#addressing-modes) examples

## Labels

### Declaration

Labels are just memory address aliases, they are placed one line before an instruction and will reference the address of that instruction
they can then be referenced by branching instructions

A Label is declared as follows

```
:LABEL
```

### Usage

A Label can be referenced by branching instructions as follows

```
:LOOP
    ADD #10
    BCC @LOOP
```

This code will loop until the value in the A Register rolls over 0xFF and sets the Carry Flag,
the `BCC` instruction will jump to the address referenced by the `LOOP` label, which in this case is the `ADD #10` instruction

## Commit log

2024-05-23 feat: instructions & begining work on the assembler
    [ROM_dump.txt]
2024-05-24 feat: finished assembly compiler v1
2024-05-27 feat: logs and documentation
    [ROM_dump.txt]
2024-05-27 feat: part list and and reworked instruction set and signals to reduce to 2 EEPROM instead of 3
    [ROM_dump.txt]
2024-05-29 feat: schematics part 1
    [ALU.kicad_sch, A_Register.kicad_sch, B_Register.kicad_sch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]
2024-05-30 chore: more docs and schematics
    [Control_Unit.kicad_sch, Output_Register.kicad_sch, Program_Counter.kicad_sch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]
2024-06-01 (WIP) feat: new instruction set, UI & address mirroring behavior
    [ROM_dump.txt]
2024-06-01 (WIP) feat: new instruction microcode finished & 16 bit bus for memory addresses
    [ROM_dump.txt]
2024-06-02 (WIP) feat: reworked compiler to support new emulator assembly
2024-06-02 feat: assembly documentation
2024-06-02 feat: updated electrical diagrams & individual part list
    [ALU.kicad_sch, A_Register.kicad_sch, B_Register.kicad_sch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]
2024-06-04 chore: full part list & memory module rework
    [Control_Unit.kicad_sch, Memory.kicad_sch]
2024-06-04 chore: reworked part list + digikey basket export
    [ROM_dump.txt, digikey_basket.csv, digikey_basket_with_spare.csv]
2024-06-04 chore: fixed address mapping in assembly documentation after memory space increase
2024-06-05 feat: updated stack pointer to use 1 IC instead of 2 for each counter
    [Stack_Pointer.kicad_sch, digikey_basket.csv, digikey_basket_with_spare.csv]
2024-12-01 Updated schematics and README
    [Clock_Module.kicad_sch, Control_Unit.kicad_sch, Memory.kicad_sch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]
2025-01-03 Fixed Control Unit schematics (CU_RST signal synchronicity)
    [Control_Unit.kicad_sch]
